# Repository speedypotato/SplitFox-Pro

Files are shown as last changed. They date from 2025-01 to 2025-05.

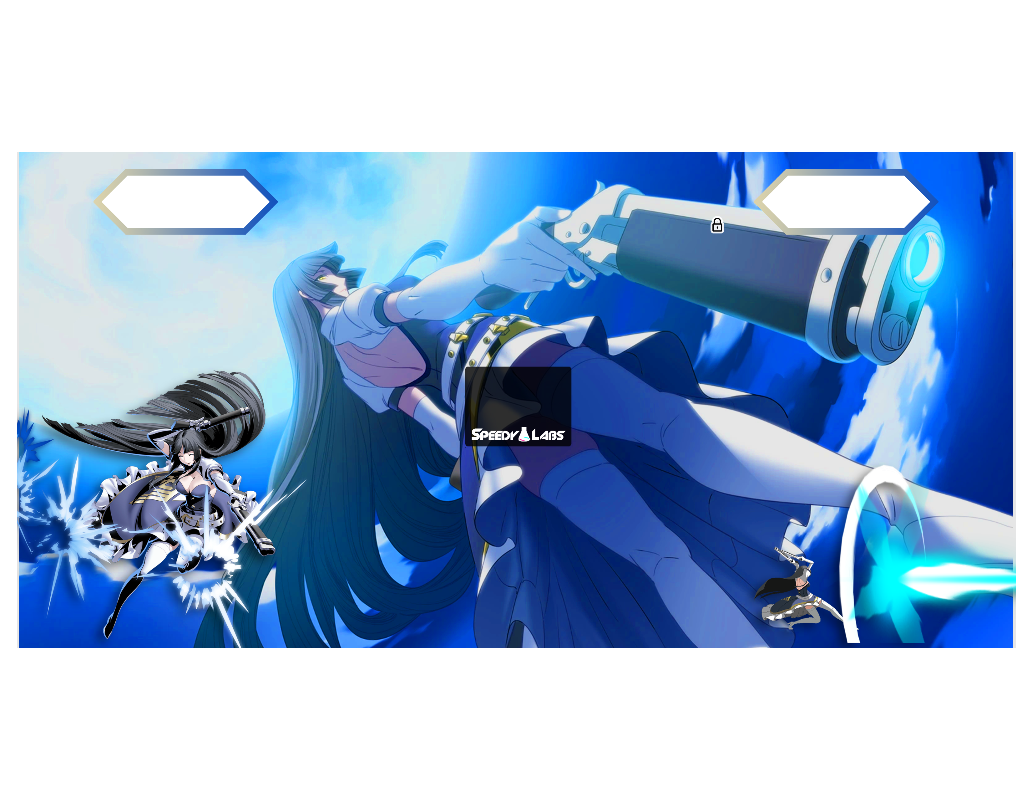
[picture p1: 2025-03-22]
art/legal_template/kaguya/speedy_labs_splitfox_template.png

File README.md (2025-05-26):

# SplitFox-Pro
Split-style Pro Leverless Controller

#### This work is licensed under a Creative Commons Attribution-NonCommercial-ShareAlike 4.0 International License.

### Prototype Run For Sale @ https://www.speedylabs.us/product/splitfox-pro-split-fighting-box-pro/ 

## What's the SplitFox Pro?
Speedy Labs introduces the SplitFox Pro - Split Fighting Box (Pro)!  This is a split layout leverless controller with 18 action buttons, 6 aux buttons, and a tournament lockout switch running on GP2040-CE.

### Design
When designing this, I had a few main goals in mind:
1. Split Layout
2. Embeddable PS Auth Dongle (non-protruding)
3. Standard or Mixbox support
4. USB C Daughterboard

Technically this would have been the LightFox Pro, but since I'm using choc v2 here due to the rumored discontinuation of Keychron LP Opticals it would feel wrong to call it that.  Hence SplitFox Pro.  The layout begins with the standard 12 button leverless layout.  I then took the 4 movement buttons and shifted them out one button space, creating the basic split layout.  I then added a button to each side of each thumb, as typical of many 16 button leverless layouts (except these only have one center thumb button, where SplitFox Pro has two).  Similarly, I added an extra button above the punch row as it's very typical to see one here in addition to a left hand pinky button because I believe that all fingers should be able to press a button at a moment's notice.

Some smaller goals, many carried over from the LightFox:
- Maintain acrylic top for artwork
- Aux buttons on both sides of controller for ease of use/preference
- OLED Display
- Mid-frame construction

### BOM
- PCBs
  - 1x SplitFox
  - 1x wasd or wasd-m
  - 1x usb-breakout
  - 1x usb-ext (optional)
- 1x OLED ZJY096-2864KSWEG41X
- Acrylics (2.5mm thickness)
  - 1x splitfox-bottom
  - 1x splitfox-top or splitfox-top-m
- CNC Aluminum (or 3D print if going for a cheaper build)
  - 1x splitfox-body
  - 1x splitfox-wasd-1_2mm or splitfox-wasd-m-1_2mm (both 1.2mm thick)
- 2x EVA Foam Feet splitfox-foot-2mm (or silicone, but it was too expensive for a small run for me)
- 23x m3x6 ultra low profile screws
- 2x m3 nut
- 18x shadow hunting switches (or any choc v2 switch)
- Keycaps
  - 4x 28.5mm
  - 14x 22.5 or 10x 22.5 + WASD (must be low profile mx stem compatible!!)
- Double sided mounting tape (Scotch 314H-MED is a good thickness for the oled in my tests)
- 2x ZH 7 Pin 10cm double headed wire (make sure you don't get the twisted cable version!! correct version e.g. https://ae01.alicdn.com/kf/S88d212727fc34138a45582e0e0a23c315.jpg)
- 3D prints
  - 1x usb-ext-bot
  - 1x usb-ext-top
  - 1x 93657A501_Nylon Unthreaded Spacer

Optionals, but things I would include normally:
- 1x 2mm hex wrench
- 1x 2m usb c cable
- 1x velcro cable tie
- 1x zipper case
- 1x shipping box
- 1x honson F5

### Basic Assembly Instructions
0. Flash SplitFox pcb
1. Plug in OLED and adhere with double sided mounting tape.
2. Plug both ZH cable into SplitFox pcb
3. Screw in SplitFox pcb into splitfox-body
4. Plug WASD ZH cable into wasd pcb
5. Screw wasd pcb into splitfox-body
6. Put splitfox-wasd-1_2mm into topside of splitfox-body, using 93657A501_Nylon Unthreaded Spacer, 1x m3x6, and 1x m3 nut to secure and sandwich together.
7. Insert shadow hunting switches.  Support sockets from backside when inserting to avoid damage.
8. Plug USB ZH cable into usb-breakout pcb
9. Screw in usb-breakout pcb into splitfox-body
10. Apply 2x splitfox-foot-2mm to splitfox-bottom
11. Screw in splitfox-bottom to splitfox-body
12. Add artwork cutout if desired
13. Screw in splitfox-top to splitfox-body

### Video Guides
SplitFox Pro Assembly & Mixbox Setup: https://youtu.be/-rr3WSn5i6s  
SplitFox Pro LED Setup (Beta): https://youtu.be/0wB09UQQ0kg

Done!  Be sure to post your builds on Discord @ https://discord.gg/MmuKd73XbY or Twitter/X and tag me @SpeedyPotato_

### Known Issues
v1.1 SplitFox fixes below issue by changing back to the crystal setup I used to use.  Could also be just a bad batch from v1 as I used a different PCBa for v1.1 too.

With v1, testing has gone fairly smoothly aside from one weird issue, where plugging in an auth dongle causes the controller to freeze/reboot.  If you leave the dongle plugged in all the time, this isn't an issue, but I hope to root cause it someday.  It might be the RP2040 crystal setup or the XC6206 being too weak, but both are also fairly tested in other controllers that don't have issues.  RP2040 crystal setup is new to me but is recommended in RP2040's hardware design guide.  XC6206 is used in production LightFox controllers and those have no issues hotplugging auth devices.

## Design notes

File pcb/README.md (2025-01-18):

# PCB

This is where the PCB source file(s) live

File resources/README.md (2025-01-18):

# Resources

This is where I dump important files during research, such as guides, datasheets, and reference circuits.

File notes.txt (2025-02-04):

shadow hunting switches + duelpad keycaps
- needs approx. 5mm above the plate to get correct height.  Maybe even lower.
- this means 2mm of alu cnc and 3mm of acryl

7 pin zh usb
1. gnd
2. gnd
3. vbus
4. d+
5. d-
6. vbus
7. gnd

7 pin zh wasd
1. rgb
2. right
3. up
4. down
5. left
6. vbus
7. gnd

and then on the mainboard, FLIP these!! due to how the cables are made

need to offset leds by 0.5mm inwards, 0.5mm downwards due to hotswap socket position

C41014 insertion depth: about 7.28
so assuming 10mm usb a male depth as standard, this means the usb should be 2.7mm away from board edge

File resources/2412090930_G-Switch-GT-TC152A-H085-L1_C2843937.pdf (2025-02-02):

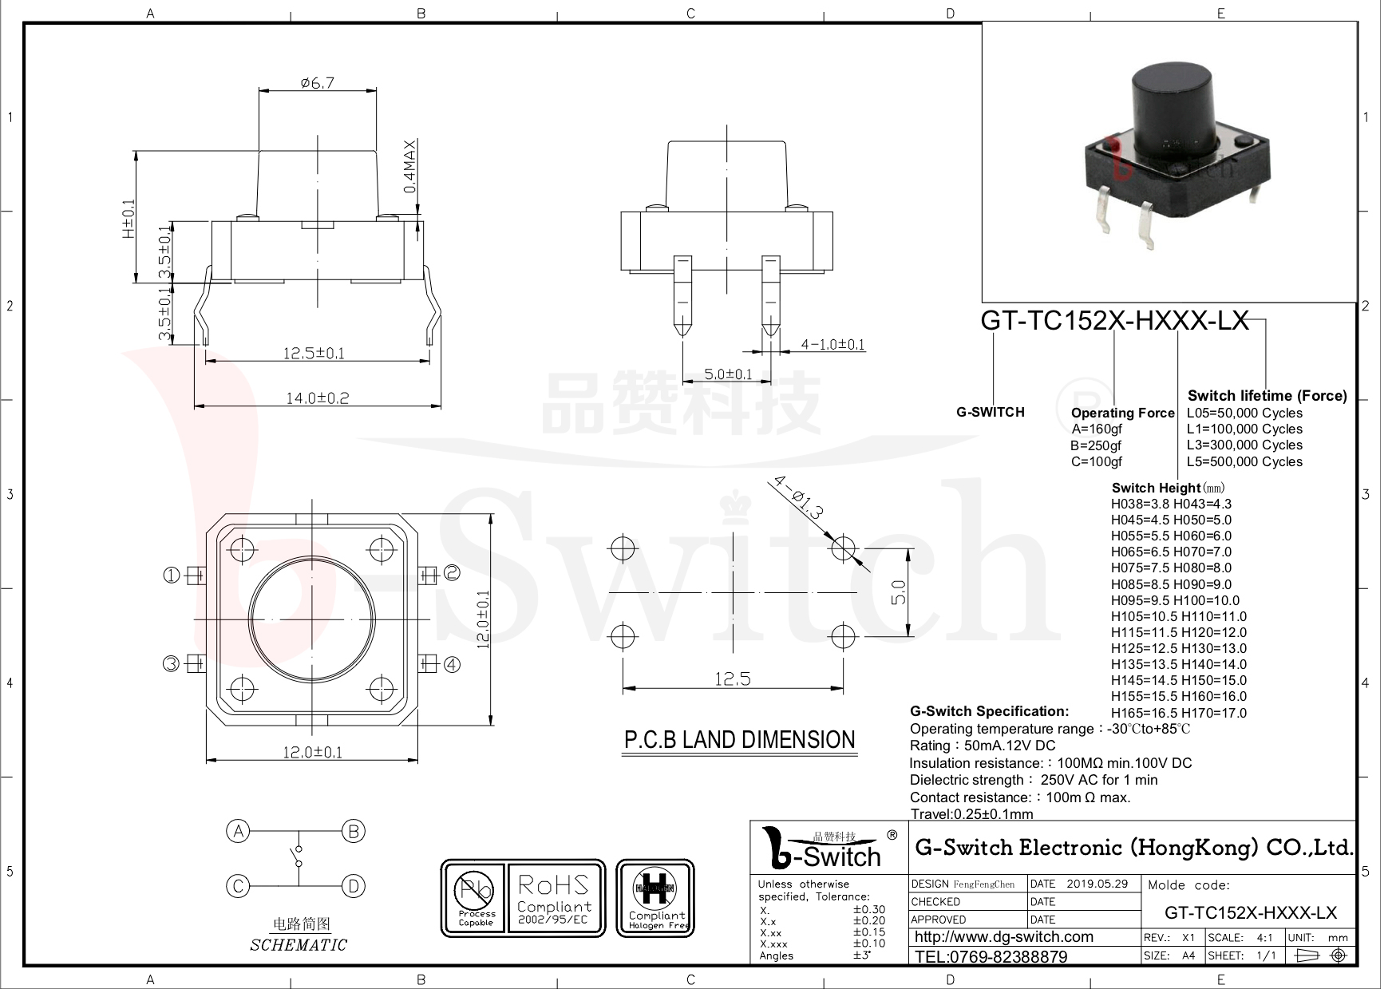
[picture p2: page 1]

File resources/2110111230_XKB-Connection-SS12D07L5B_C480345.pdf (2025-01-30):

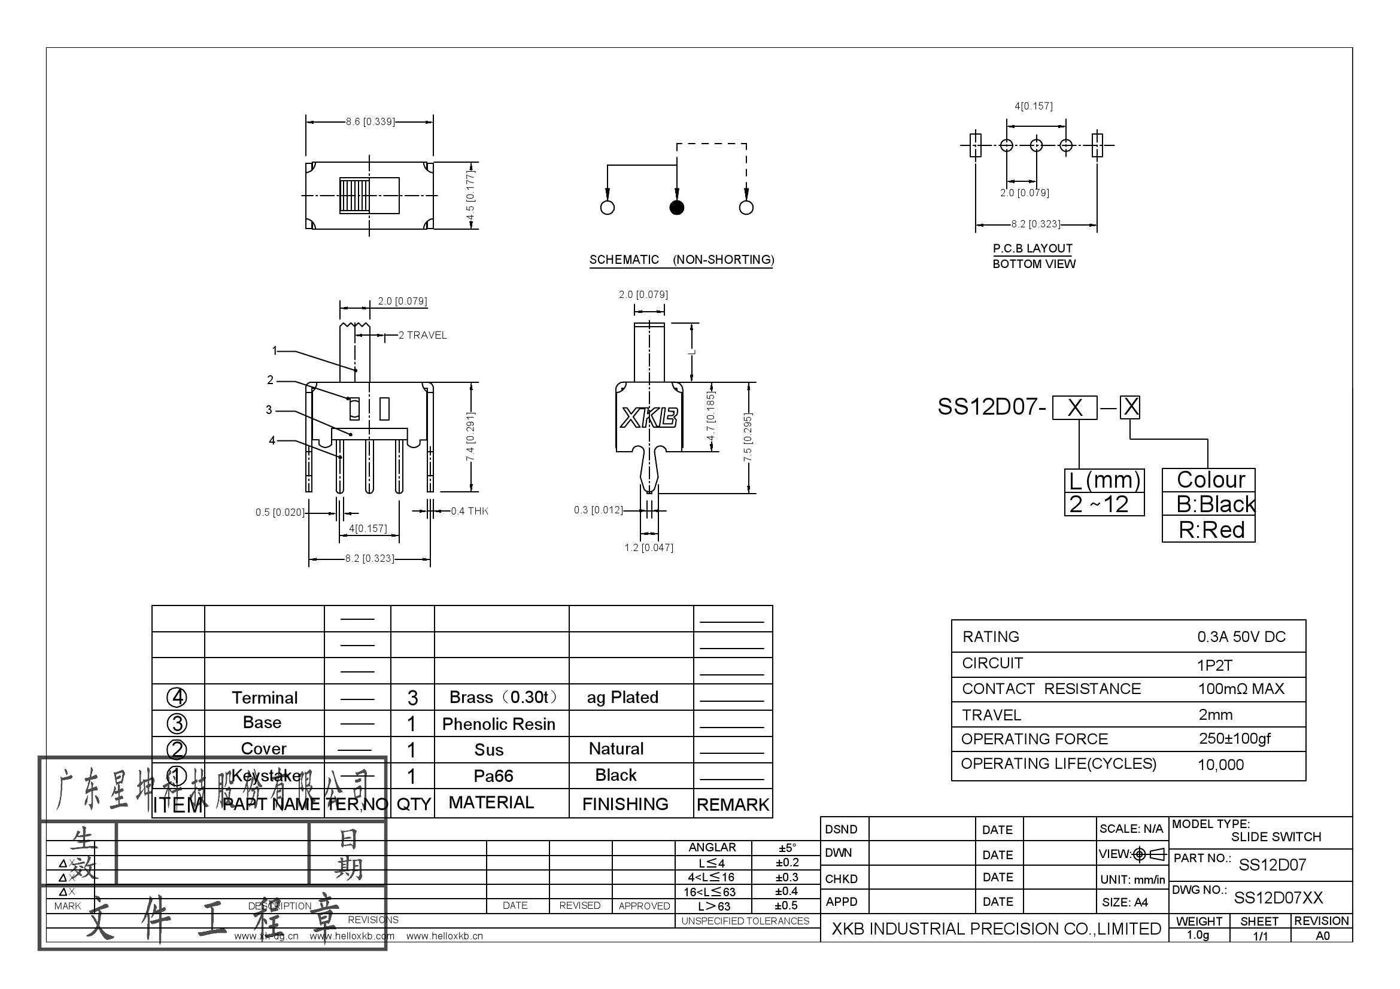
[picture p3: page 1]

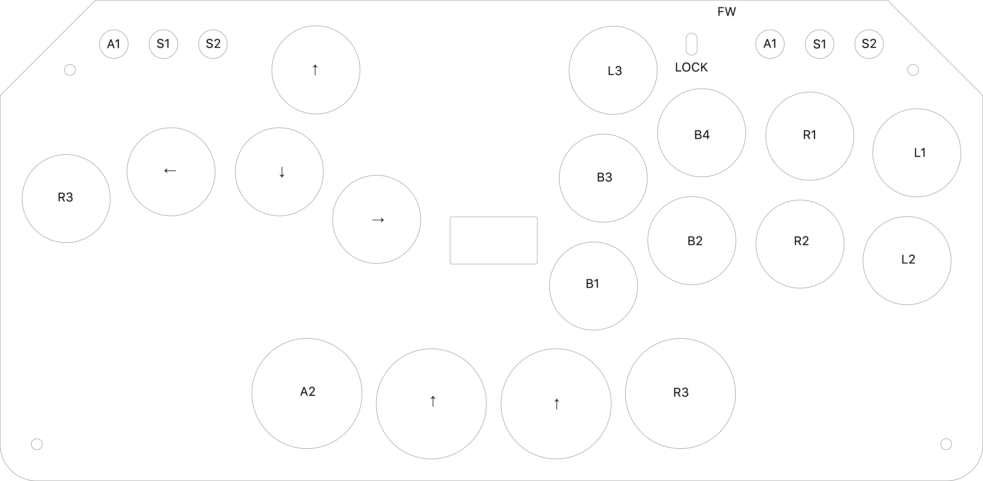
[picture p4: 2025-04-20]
docs/button layout.png

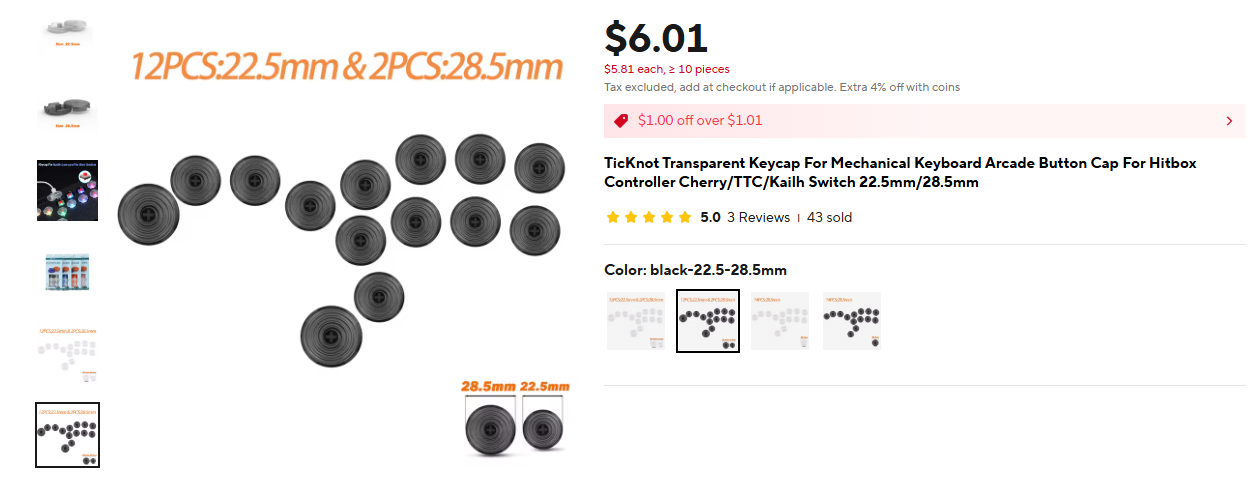
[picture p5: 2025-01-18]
video/screenshots/5_keycapsize.png

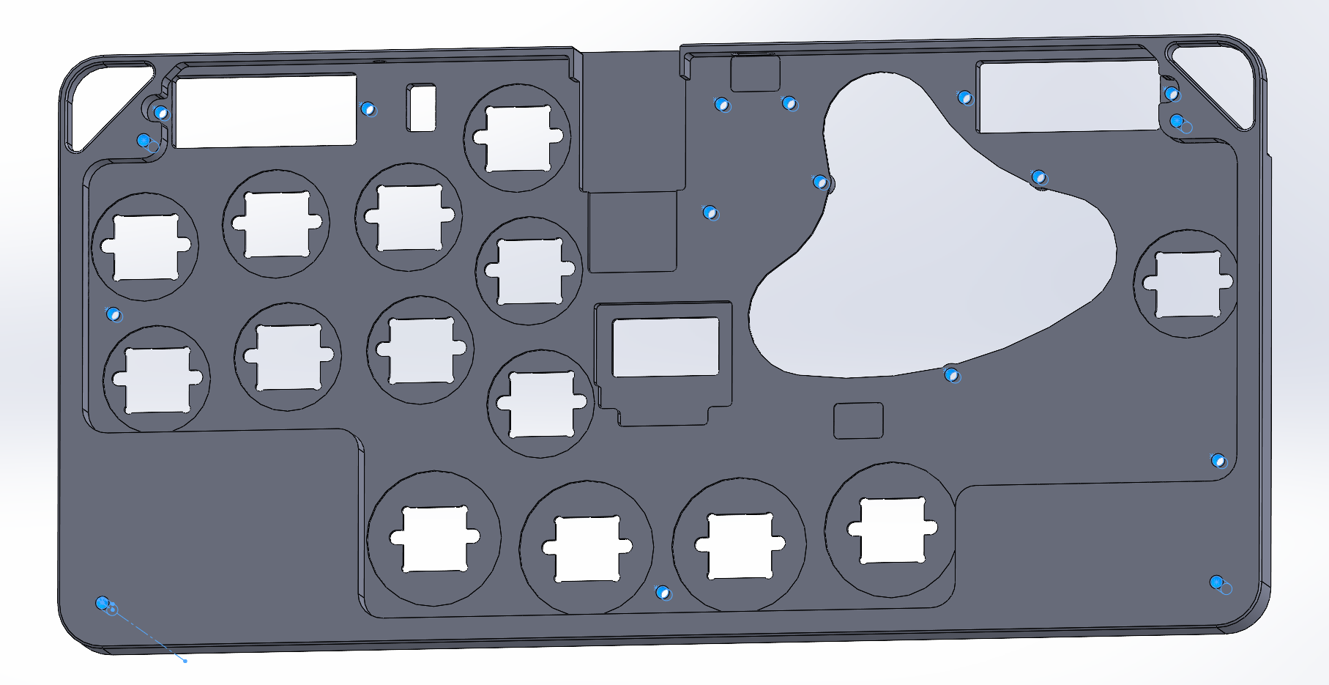
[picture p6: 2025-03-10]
cad/export/aluminum/splitfox-body-m3.png

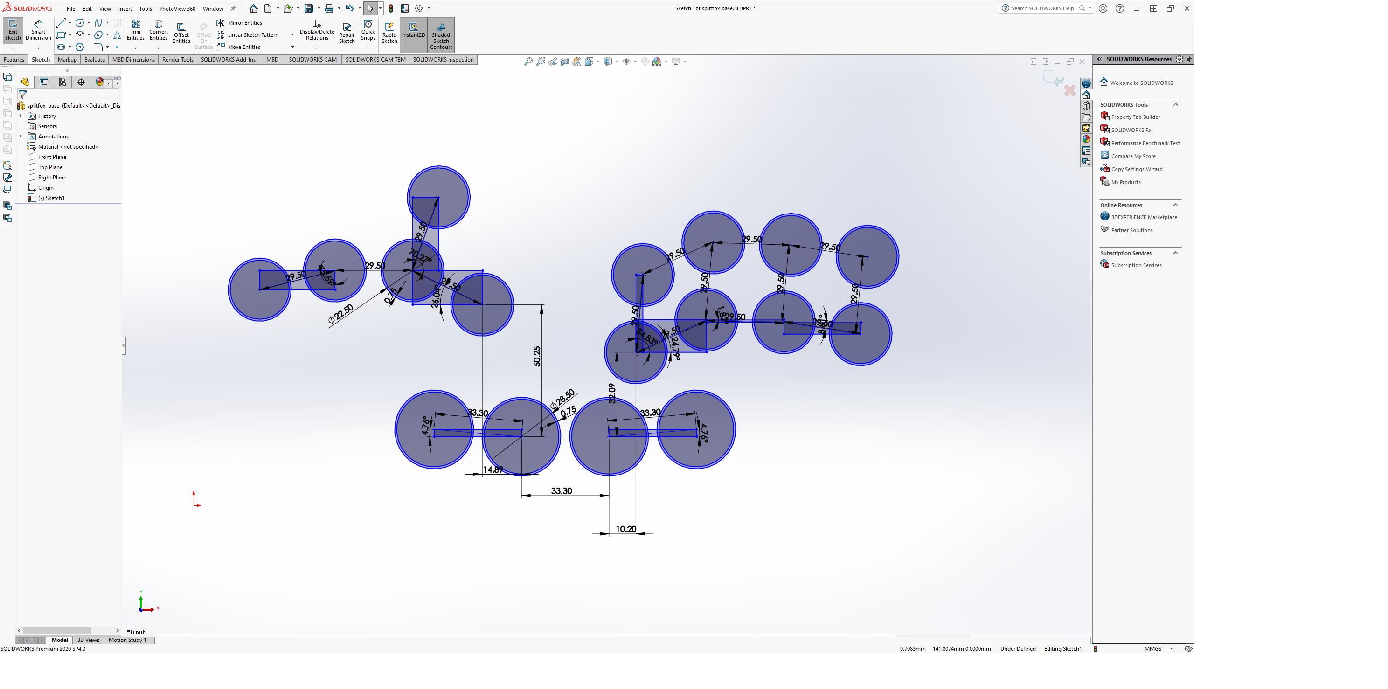
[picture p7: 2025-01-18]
video/screenshots/6_layout.png

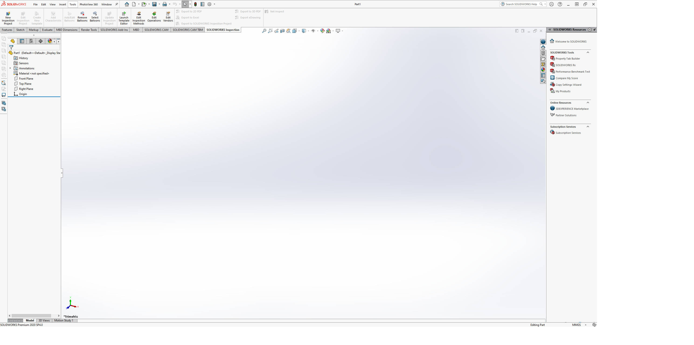
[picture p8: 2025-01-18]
video/screenshots/3_solidworks.png

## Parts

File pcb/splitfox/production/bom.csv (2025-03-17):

Designator | Footprint | Quantity | Value | LCSC Part #
C1, C10, C13, C16, C18, C19, C20, C21, C24, C25, C26, C27, C28, C29, C3, C30, C31, C32, C33, C34, C35, C36, C37, C38, C39, C40, C41, C42, C43, C44, C45, C46, C47, C48, C49, C50, C51, C52, C53, C54, C8 | 0402 | 41 | 100nF | C1525
C11, C12, C14, C15, C2, C4, C5, C9 | 0402 | 8 | 1uF | C52923
C17, C22 | 0402 | 2 | 4.7uF | C466620
C23 | 0402 | 1 | 2.2uF | C2976056
C6, C7 | 0402 | 2 | 30pF | C1570
CH1, CH10, CH11, CH12, CH13, CH14, CH2, CH3, CH4, CH5, CH6, CH7, CH8, CH9 | SW_choc_v2_HS_CPG135001S30_1u | 14 | choc_v1_SW_HS | C5333465
CN1, CN2 | CONN-SMD_S7B-ZR-SM4A-TF-LF-SN | 2 | S7B-ZR-SM4A-TF(LF)(SN)_C5118704 | C5118704
D1 | D_SOD-123 | 1 | ESD | C81598
F1, F2, F3 | 1206 | 3 | 500mA | C720075
FPC1 | FPC-SMD_30P-P0.50_0.5-30P-XJH2.0-043 | 1 | 0.5-30P XJH2.0 043 | C5373440
LED1, LED10, LED11, LED12, LED13, LED14, LED15, LED16, LED17, LED18, LED19, LED2, LED20, LED21, LED22, LED23, LED24, LED25, LED26, LED27, LED28, LED3, LED4, LED5, LED6, LED7, LED8, LED9 | LED_6028R | 28 | SK6812MINI-E | C5149201
R1, R2, R3, R4 | 0402 | 4 | 27R | C137890
R10 | 0402 | 1 | 910K | C25800
R11 | 0402 | 1 | 470R | C25117
R12 | 0402 | 1 | 4.7M | C474132
R13, R14 | 0402 | 2 | 5k1 | C25905
R5, R6 | 0402 | 2 | 1k | C11702
R7 | 0402 | 1 | 4K7 | C25900
R8, R9 | 0402 | 2 | 10k | C25744
SW1 | SW-SMD_TS24CA | 1 | TS24CA | C393942
SW2 | SW-TH_SS-12D07-X-X | 1 | SS-12D07-L5-B | C480345
SW3, SW4, SW5, SW6, SW7, SW8 | SW-TH_4P-L12.0-W12.0-P5.00-LS12.5 | 6 | GT-TC152A-H085-L1 | C2843937
U1 | RP2040-QFN-56 | 1 | RP2040 | C2040
U2 | SOT-23-5_L2.9-W1.6-P0.95-LS2.8-BR | 1 | SN74LV1T34DBVR | C100024
U3 | SOIC-8_5.23x5.23mm_P1.27mm | 1 | W25Q128JVS | C131025
U4 | SOT-23 | 1 | XC6206PxxxMR-Regulator_Linear | C5446
U5 | SOT-23-6 | 1 | USBLC6-2SC6 | C2827654
USB1 | USB-A-SMD_C41014 | 1 | USB-AF-90-10X15.7-H5.72-CB | C41014
USBC1 | USB-C_SMD-TYPE-C-31-M-12 | 1 | TYPE-C-31-M-12 | C165948
Y1 | Crystal_SMD_3225-4Pin_3.2x2.5mm | 1 | 12MHz | C9002

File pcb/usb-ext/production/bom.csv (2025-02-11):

Designator | Footprint | Quantity | Value | LCSC Part #
USB1 | USB-SMD_AM180CB | 1 | AM 180°CB | C2681565
USB2 | USB-A-SMD_C41014 | 1 | USB-AF-90-10X15.7-H5.72-CB | C41014

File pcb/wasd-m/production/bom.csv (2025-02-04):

Designator | Footprint | Quantity | Value | LCSC Part #
C1, C2, C3, C4 | 0402 | 4 | 100nF | C1525
CH1, CH2, CH3, CH4 | SW_choc_v2_HS_CPG135001S30_1u | 4 | choc_v1_SW_HS | C5333465
CN1 | CONN-SMD_S7B-ZR-SM4A-TF-LF-SN | 1 | S7B-ZR-SM4A-TF(LF)(SN)_C5118704 | C5118704
LED1, LED2, LED3, LED4 | LED_choc_6028R | 4 | choc_SK6812MINI-E | C5149201

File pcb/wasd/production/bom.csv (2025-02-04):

Designator | Footprint | Quantity | Value | LCSC Part #
C1, C2, C3, C4, C5, C6, C7, C8 | 0402 | 8 | 100nF | C1525
CH1, CH2, CH3, CH4 | SW_choc_v2_HS_CPG135001S30_1u | 4 | choc_v1_SW_HS | C5333465
CN1 | CONN-SMD_S7B-ZR-SM4A-TF-LF-SN | 1 | S7B-ZR-SM4A-TF(LF)(SN)_C5118704 | C5118704
LED1, LED2, LED3, LED4, LED5, LED6, LED7, LED8 | LED_choc_6028R | 8 | choc_SK6812MINI-E | C5149201

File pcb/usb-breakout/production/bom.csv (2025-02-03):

Designator | Footprint | Quantity | Value | LCSC Part #
CN1 | CONN-SMD_S7B-ZR-SM4A-TF-LF-SN | 1 | S7B-ZR-SM4A-TF(LF)(SN)_C5118704 | C5118704
R1, R2 | 0402 | 2 | 5k1 | C25905
USBC1 | USB-C_SMD-TYPE-C-31-M-12 | 1 | TYPE-C-31-M-12 | C165948

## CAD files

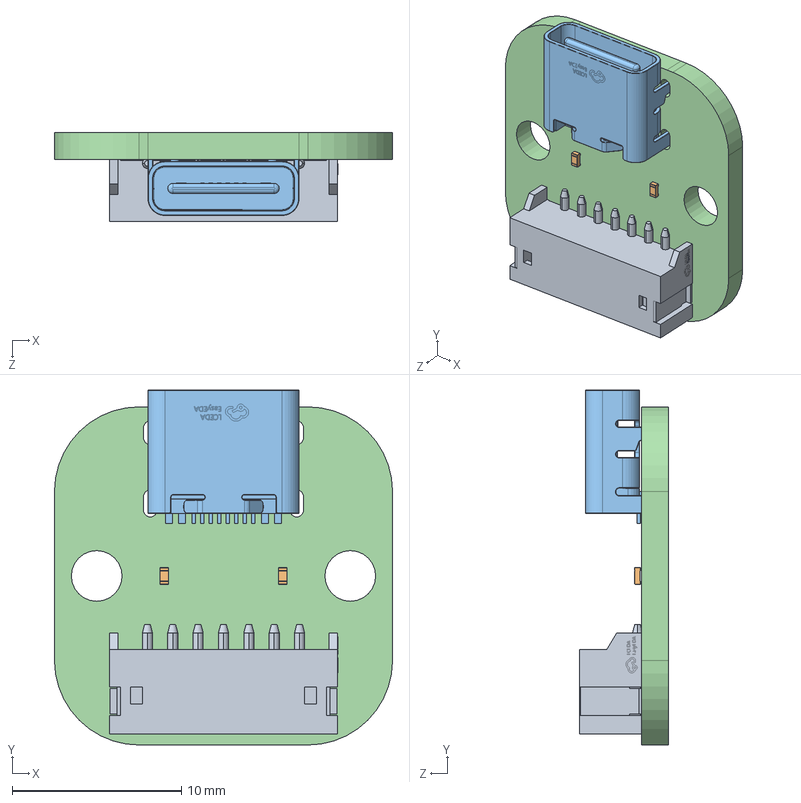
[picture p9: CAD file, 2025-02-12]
pcb/usb-breakout/usb-breakout-pcb.SLDASM
20.0 x 21.0 x 5.25 mm
CONN-SMD_S7B-ZR-SM4A-TF-LF-SN-1.step
R_0402_1005Metric-1.step x 2
USB-C_SMD-TYPE-C-31-M-12-2.step
_autosave-usb-breakout_PCB.step

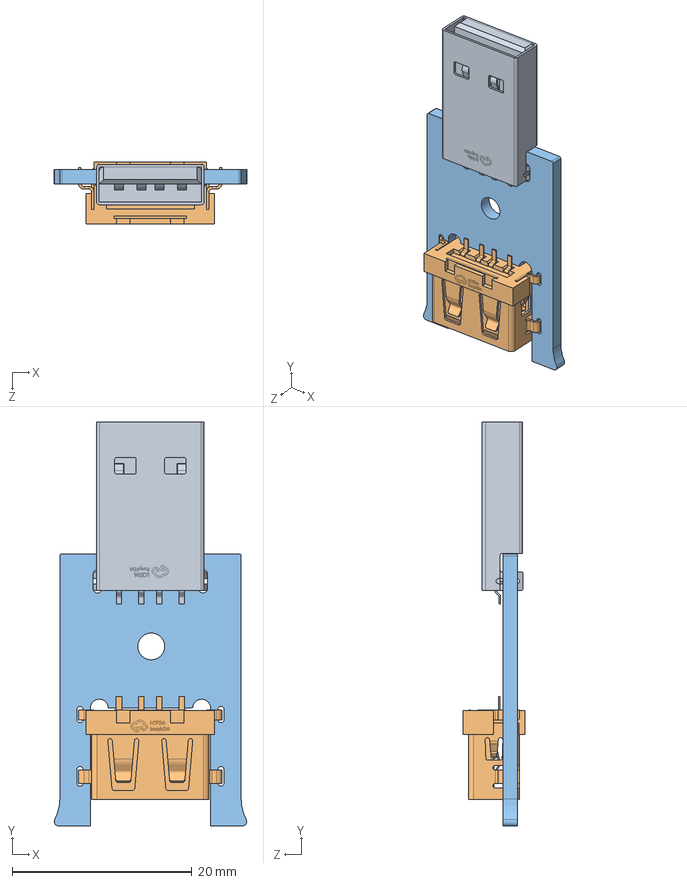
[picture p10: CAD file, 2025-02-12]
pcb/usb-ext/usb-ext-pcb.SLDASM
21.4 x 45.0 x 6.88 mm
USB-SMD_AM180CB-0.step
USB-A-SMD_4P-L13.1-W10.0-H5.7-LS15.7-5.step
_autosave-usb-ext_PCB.step

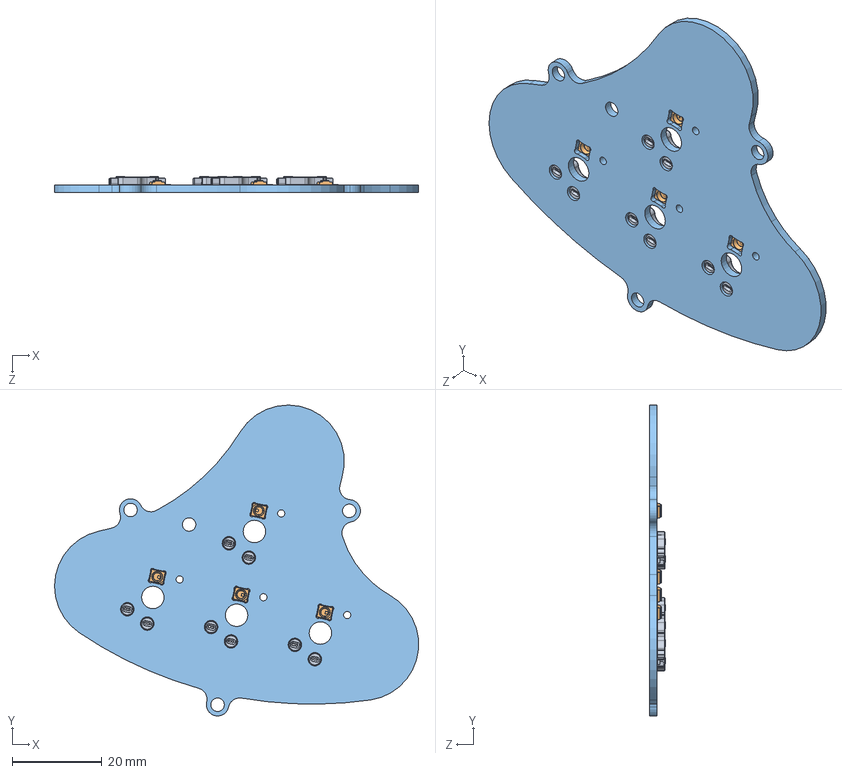
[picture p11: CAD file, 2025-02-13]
pcb/wasd-m/wasd-m-pcb.SLDASM
81.0 x 69.1 x 3.49 mm
HS_Kailh_Choc v4.step x 4
LED_SK6812MINI-E v2.step x 4
_autosave-wasd-m_PCB.step

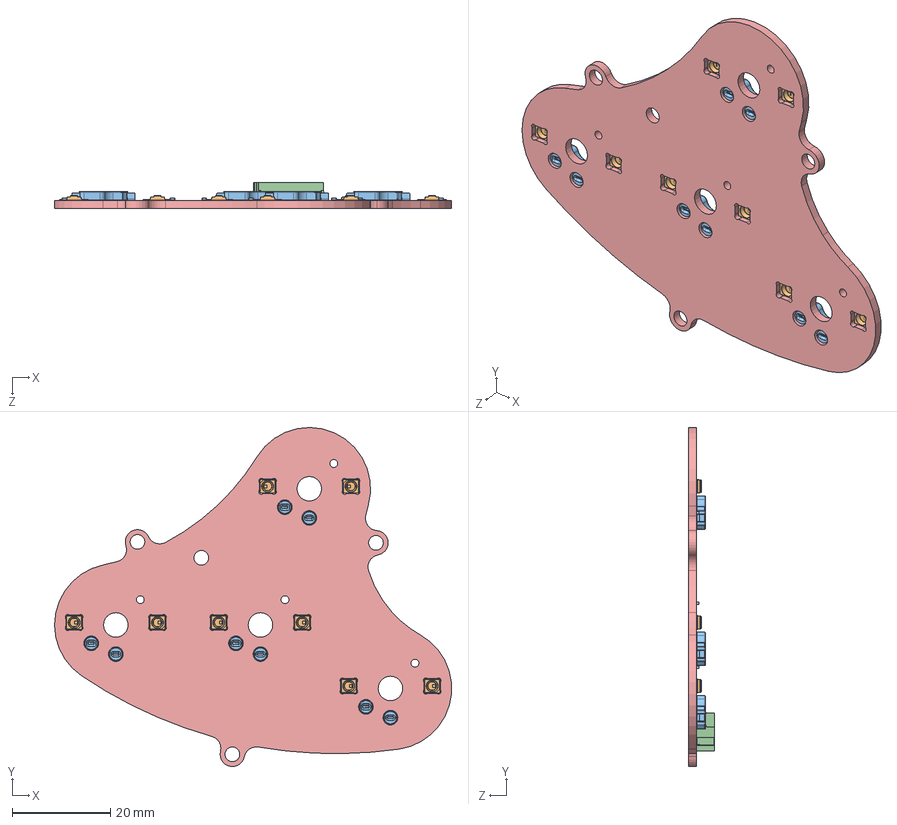
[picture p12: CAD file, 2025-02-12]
pcb/wasd/wasd-pcb.SLDASM
81.0 x 69.1 x 5.25 mm
C_0402_1005Metric-0.step x 8
LED_SK6812MINI-E v2.step x 8
HS_Kailh_Choc v4.step x 4
CONN-SMD_S7B-ZR-SM4A-TF-LF-SN-1.step
_autosave-wasd_PCB.step

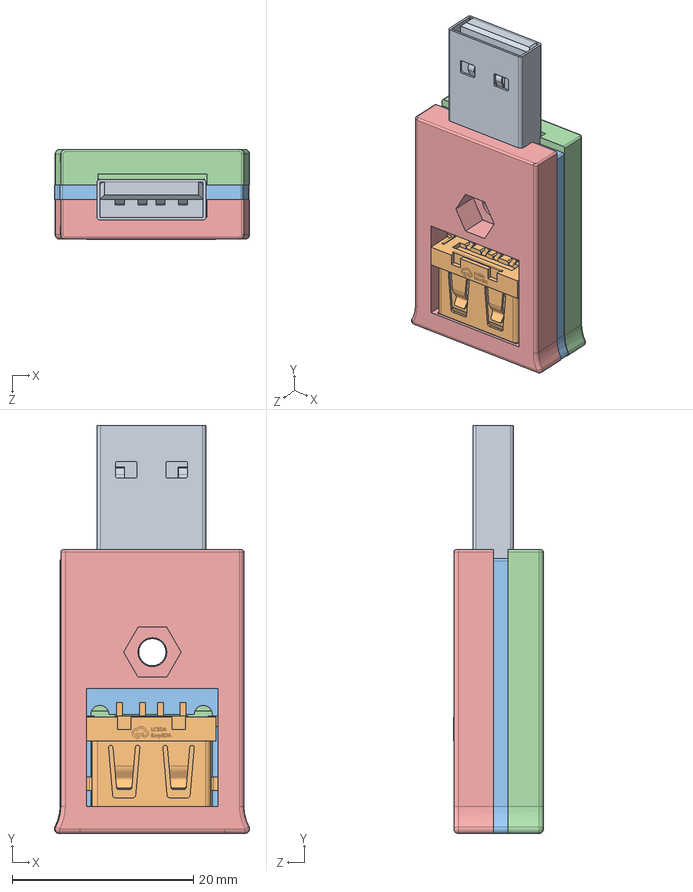
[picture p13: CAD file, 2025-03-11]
cad/usb-ext-assem.SLDASM
21.5 x 45.0 x 9.93 mm
USB-SMD_AM180CB-0.step
USB-A-SMD_4P-L13.1-W10.0-H5.7-LS15.7-5.step
_autosave-usb-ext_PCB.step
usb-ext-bot
usb-ext-top

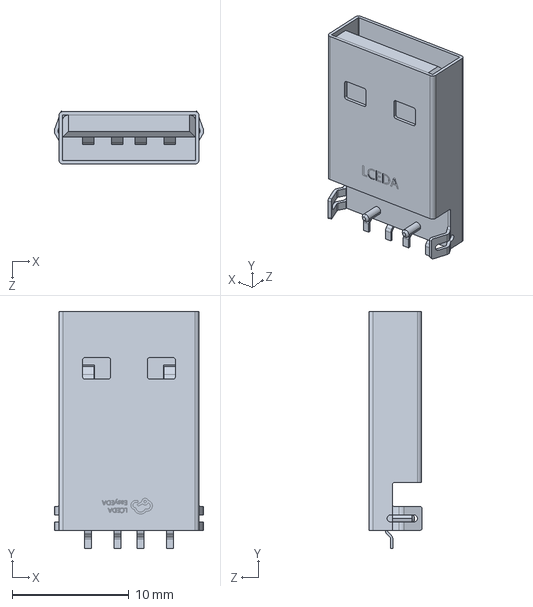
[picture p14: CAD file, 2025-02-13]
cad/usb-ext.SLDASM
12.8 x 20.3 x 4.55 mm

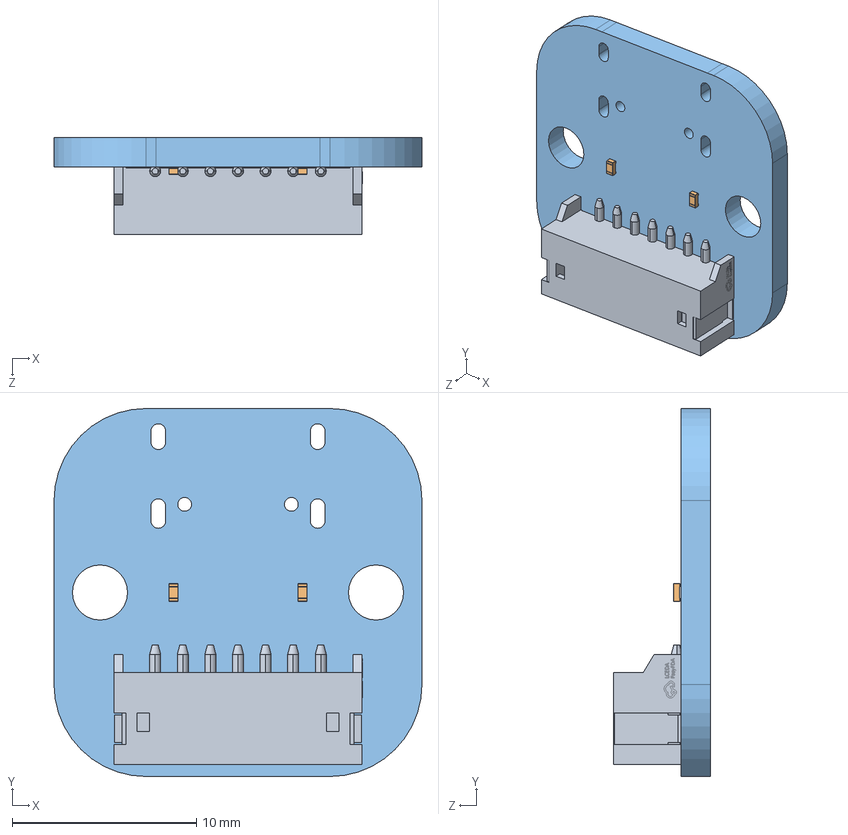
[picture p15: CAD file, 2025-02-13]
cad/usb-breakout.SLDASM
20.0 x 20.0 x 5.25 mm
CONN-SMD_S7B-ZR-SM4A-TF-LF-SN-7.step
R_0402_1005Metric-1.step x 2
usb-breakout_PCB.step

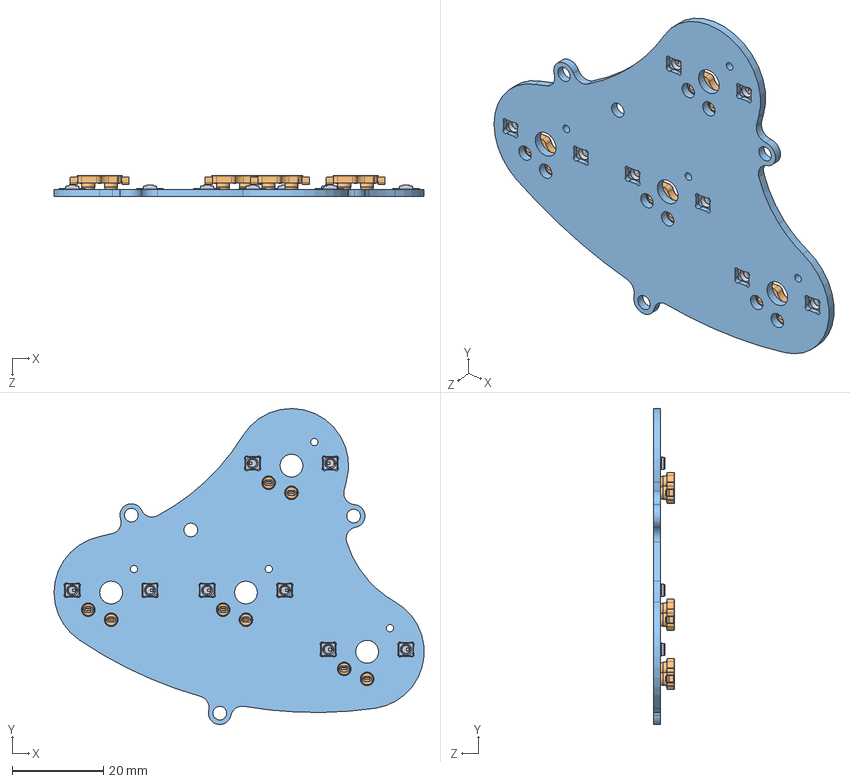
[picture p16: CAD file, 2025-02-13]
cad/wasd.SLDASM
81.0 x 69.1 x 4.69 mm
LED_SK6812MINI-E v2.step x 8
HS_Kailh_Choc v4.step x 4
_autosave-wasd_PCB.step

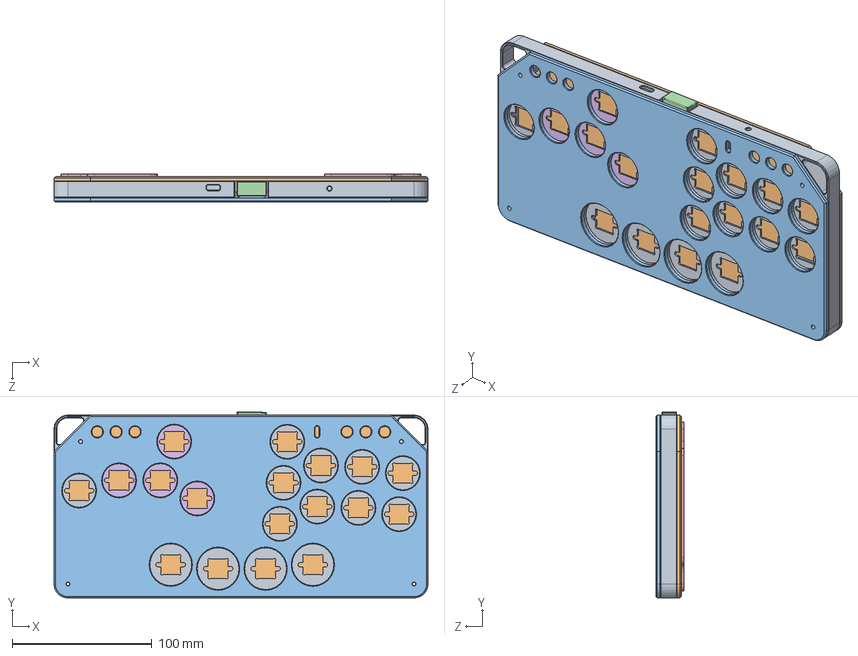
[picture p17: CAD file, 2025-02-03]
cad/splitfox.SLDASM
267.8 x 133.1 x 20.3 mm
splitfox-body
splitfox-bottom
splitfox-top
honson-f5
splitfox-foot
splitfox-wasd

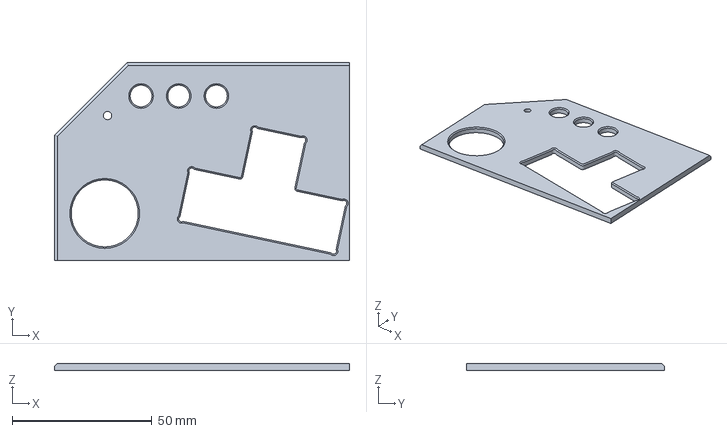
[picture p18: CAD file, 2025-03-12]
cad/3d-print-test/splitfox-top-m-2_5.3MF
105.7 x 70.9 x 2.50 mm

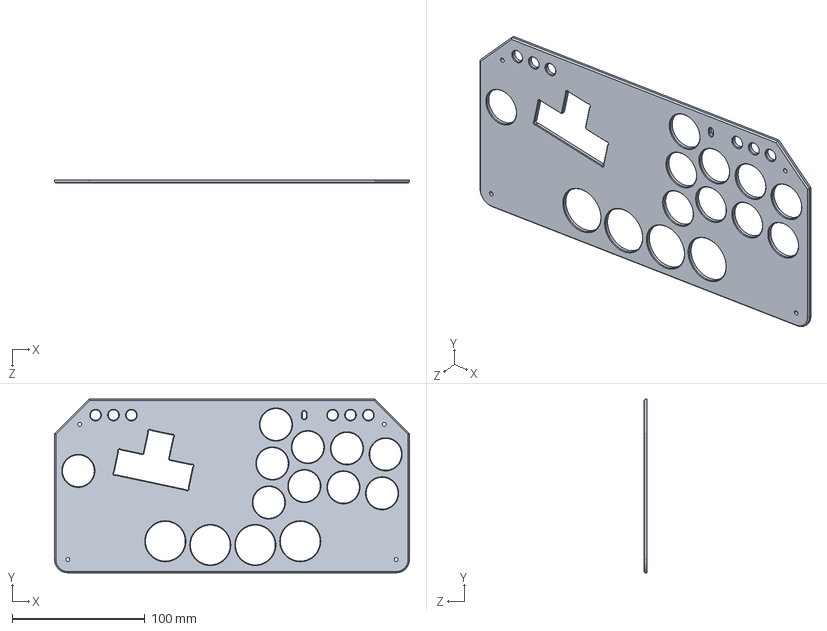
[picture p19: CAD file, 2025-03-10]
cad/export/acrylic/splitfox-top-m.STEP
267.8 x 131.0 x 2.50 mm

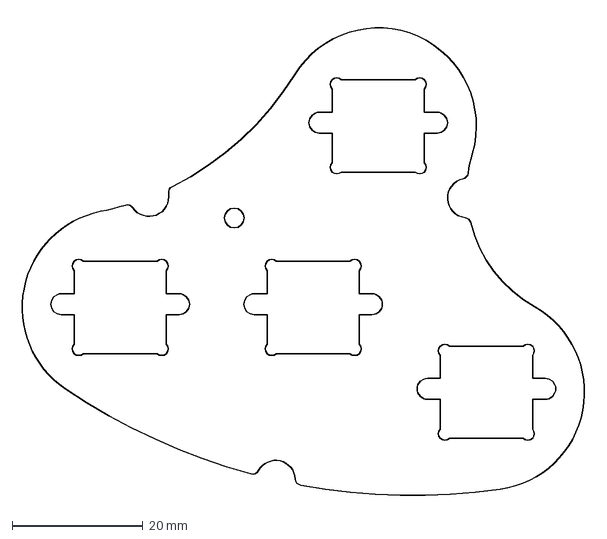
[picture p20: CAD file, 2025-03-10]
cad/export/aluminum/splitfox-wasd-1_2mm.DXF
87.8 x 73.8 mm

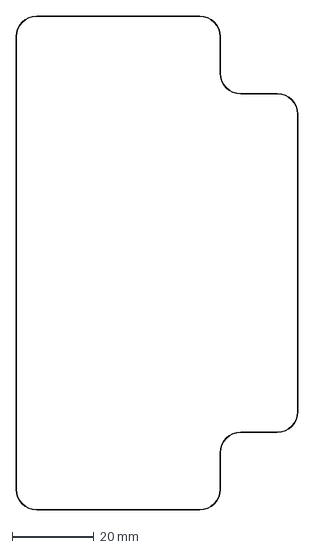
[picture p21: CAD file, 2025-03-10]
cad/export/rubber/splitfox-foot-2mm.DXF
69.0 x 121.0 mm

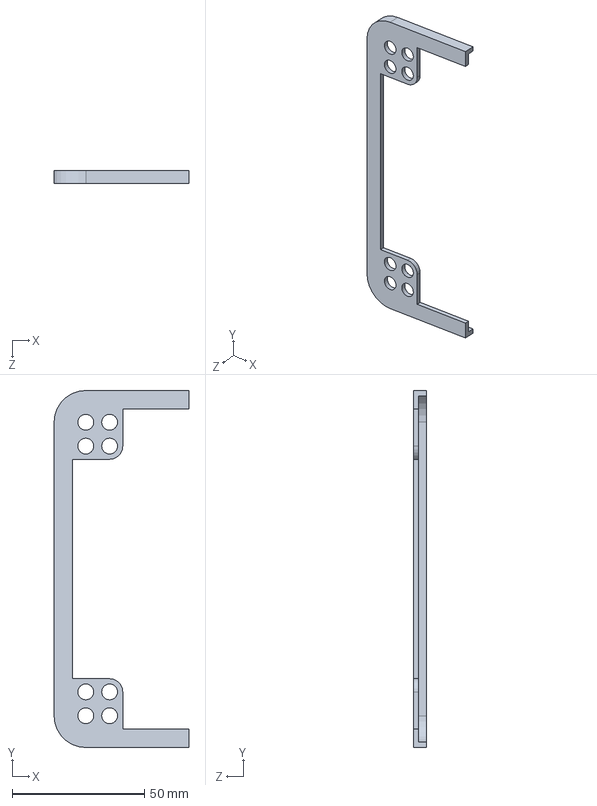
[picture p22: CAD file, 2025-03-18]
cad/splitfox-foot-tool.SLDPRT
51.0 x 135.0 x 5.00 mm

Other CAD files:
pcb/wasd/wasd.step
resources/R16-facetemplate.dwg
resources/reference/multra.SLDPRT
cad/3d-print-test/splitfox-foot.3MF
cad/3d-print-test/splitfox-body - Copy (2).3MF
cad/3d-print-test/splitfox-body - Copy (2).SLDPRT
cad/3d-print-test/splitfox-body - Copy (3).3MF
cad/3d-print-test/splitfox-body - Copy (3).SLDPRT
cad/3d-print-test/splitfox-body - Copy.3MF
cad/3d-print-test/splitfox-body - Copy.SLDPRT
cad/3d-print-test/splitfox-body.3MF
cad/3d-print-test/splitfox-body.SLDPRT
cad/3d-print-test/splitfox-bottom.DXF
cad/3d-print-test/splitfox-top-m.DXF
cad/3d-print-test/splitfox-top.DXF
cad/3d-print-test/splitfox-wasd-m.3MF
cad/3d-print-test/splitfox-wasd.3MF
cad/export/3dprint/93657A501_Nylon Unthreaded Spacer.3MF
cad/export/3dprint/splitfox-foot-tool.3MF
cad/export/3dprint/usb-ext-bot.3MF
cad/export/3dprint/usb-ext-top.3MF
cad/export/acrylic/splitfox-bottom.STEP
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

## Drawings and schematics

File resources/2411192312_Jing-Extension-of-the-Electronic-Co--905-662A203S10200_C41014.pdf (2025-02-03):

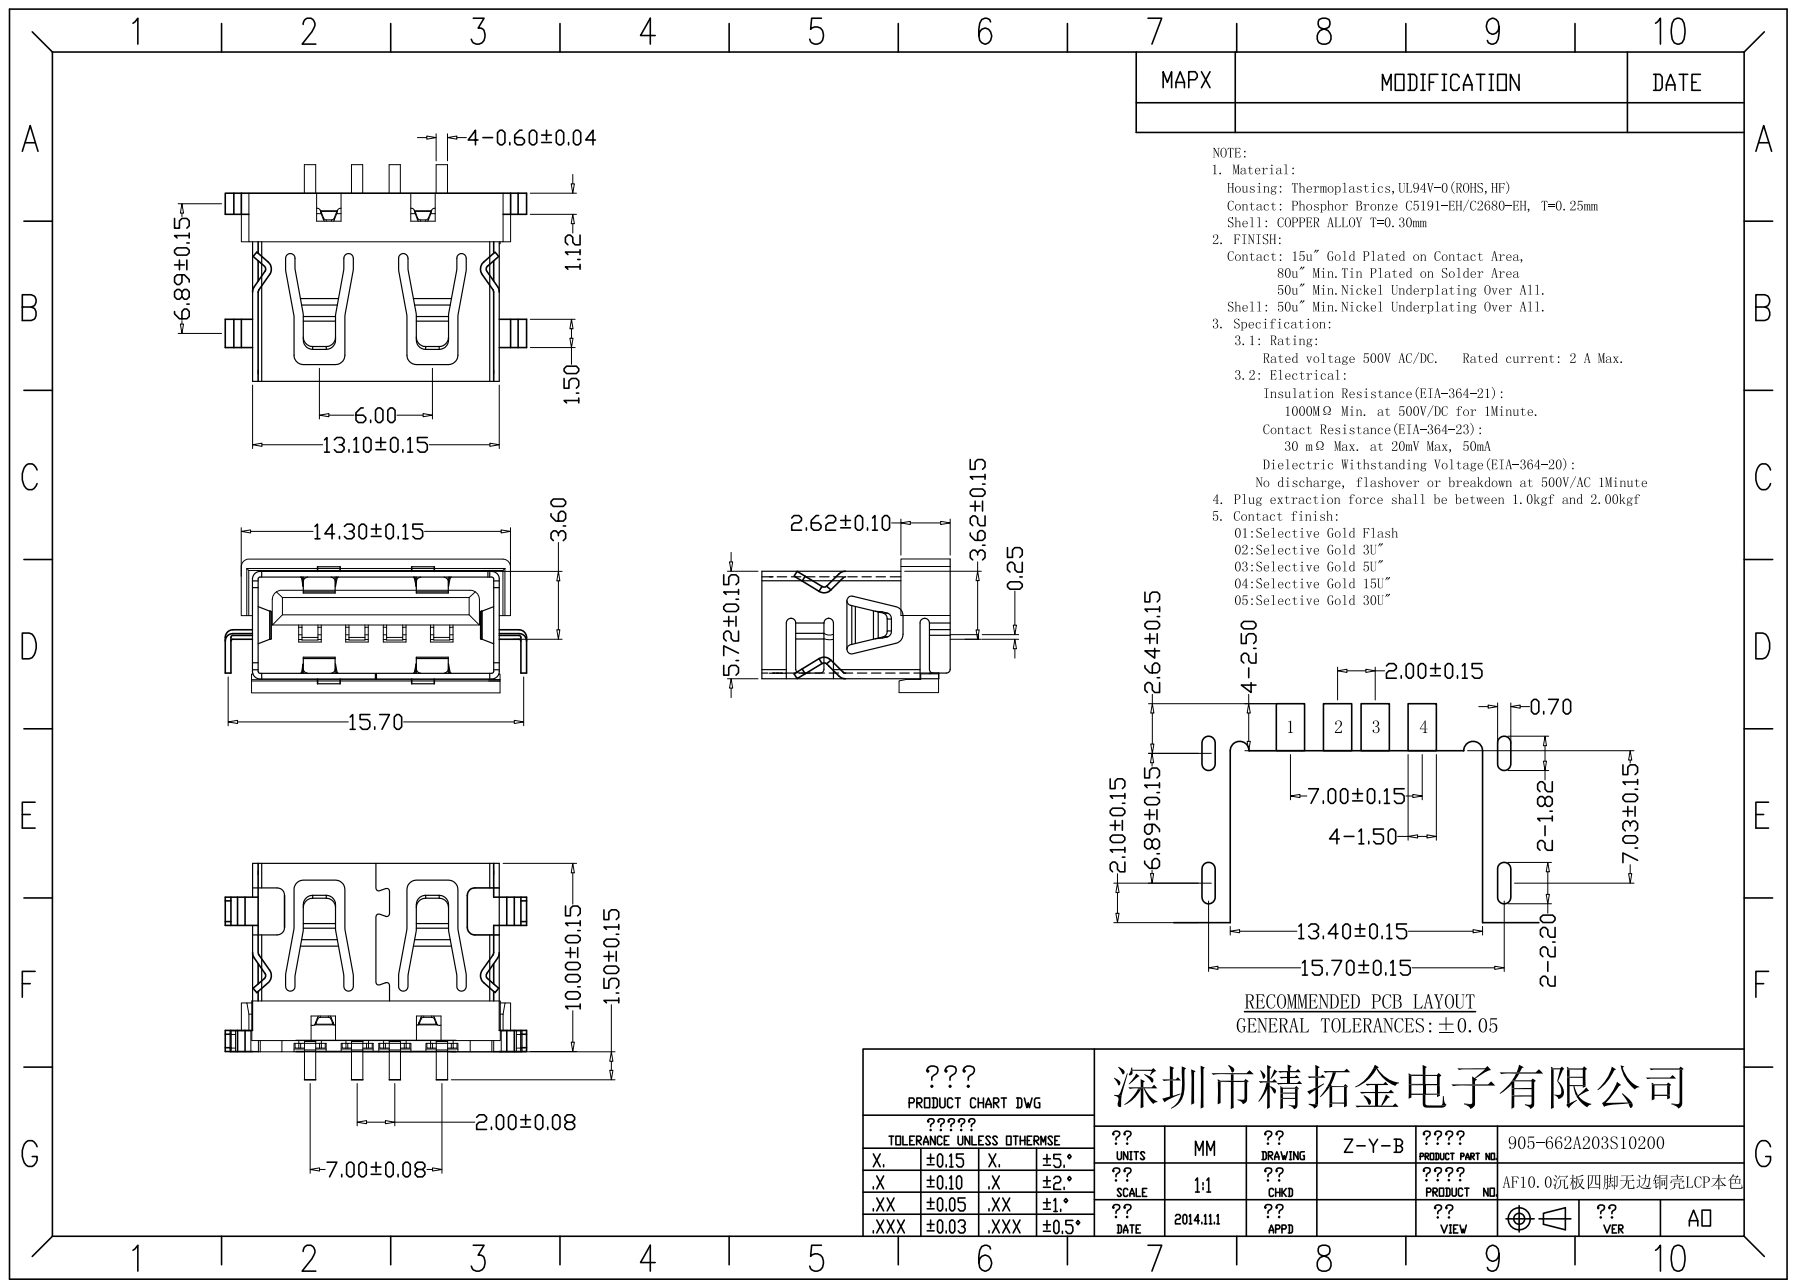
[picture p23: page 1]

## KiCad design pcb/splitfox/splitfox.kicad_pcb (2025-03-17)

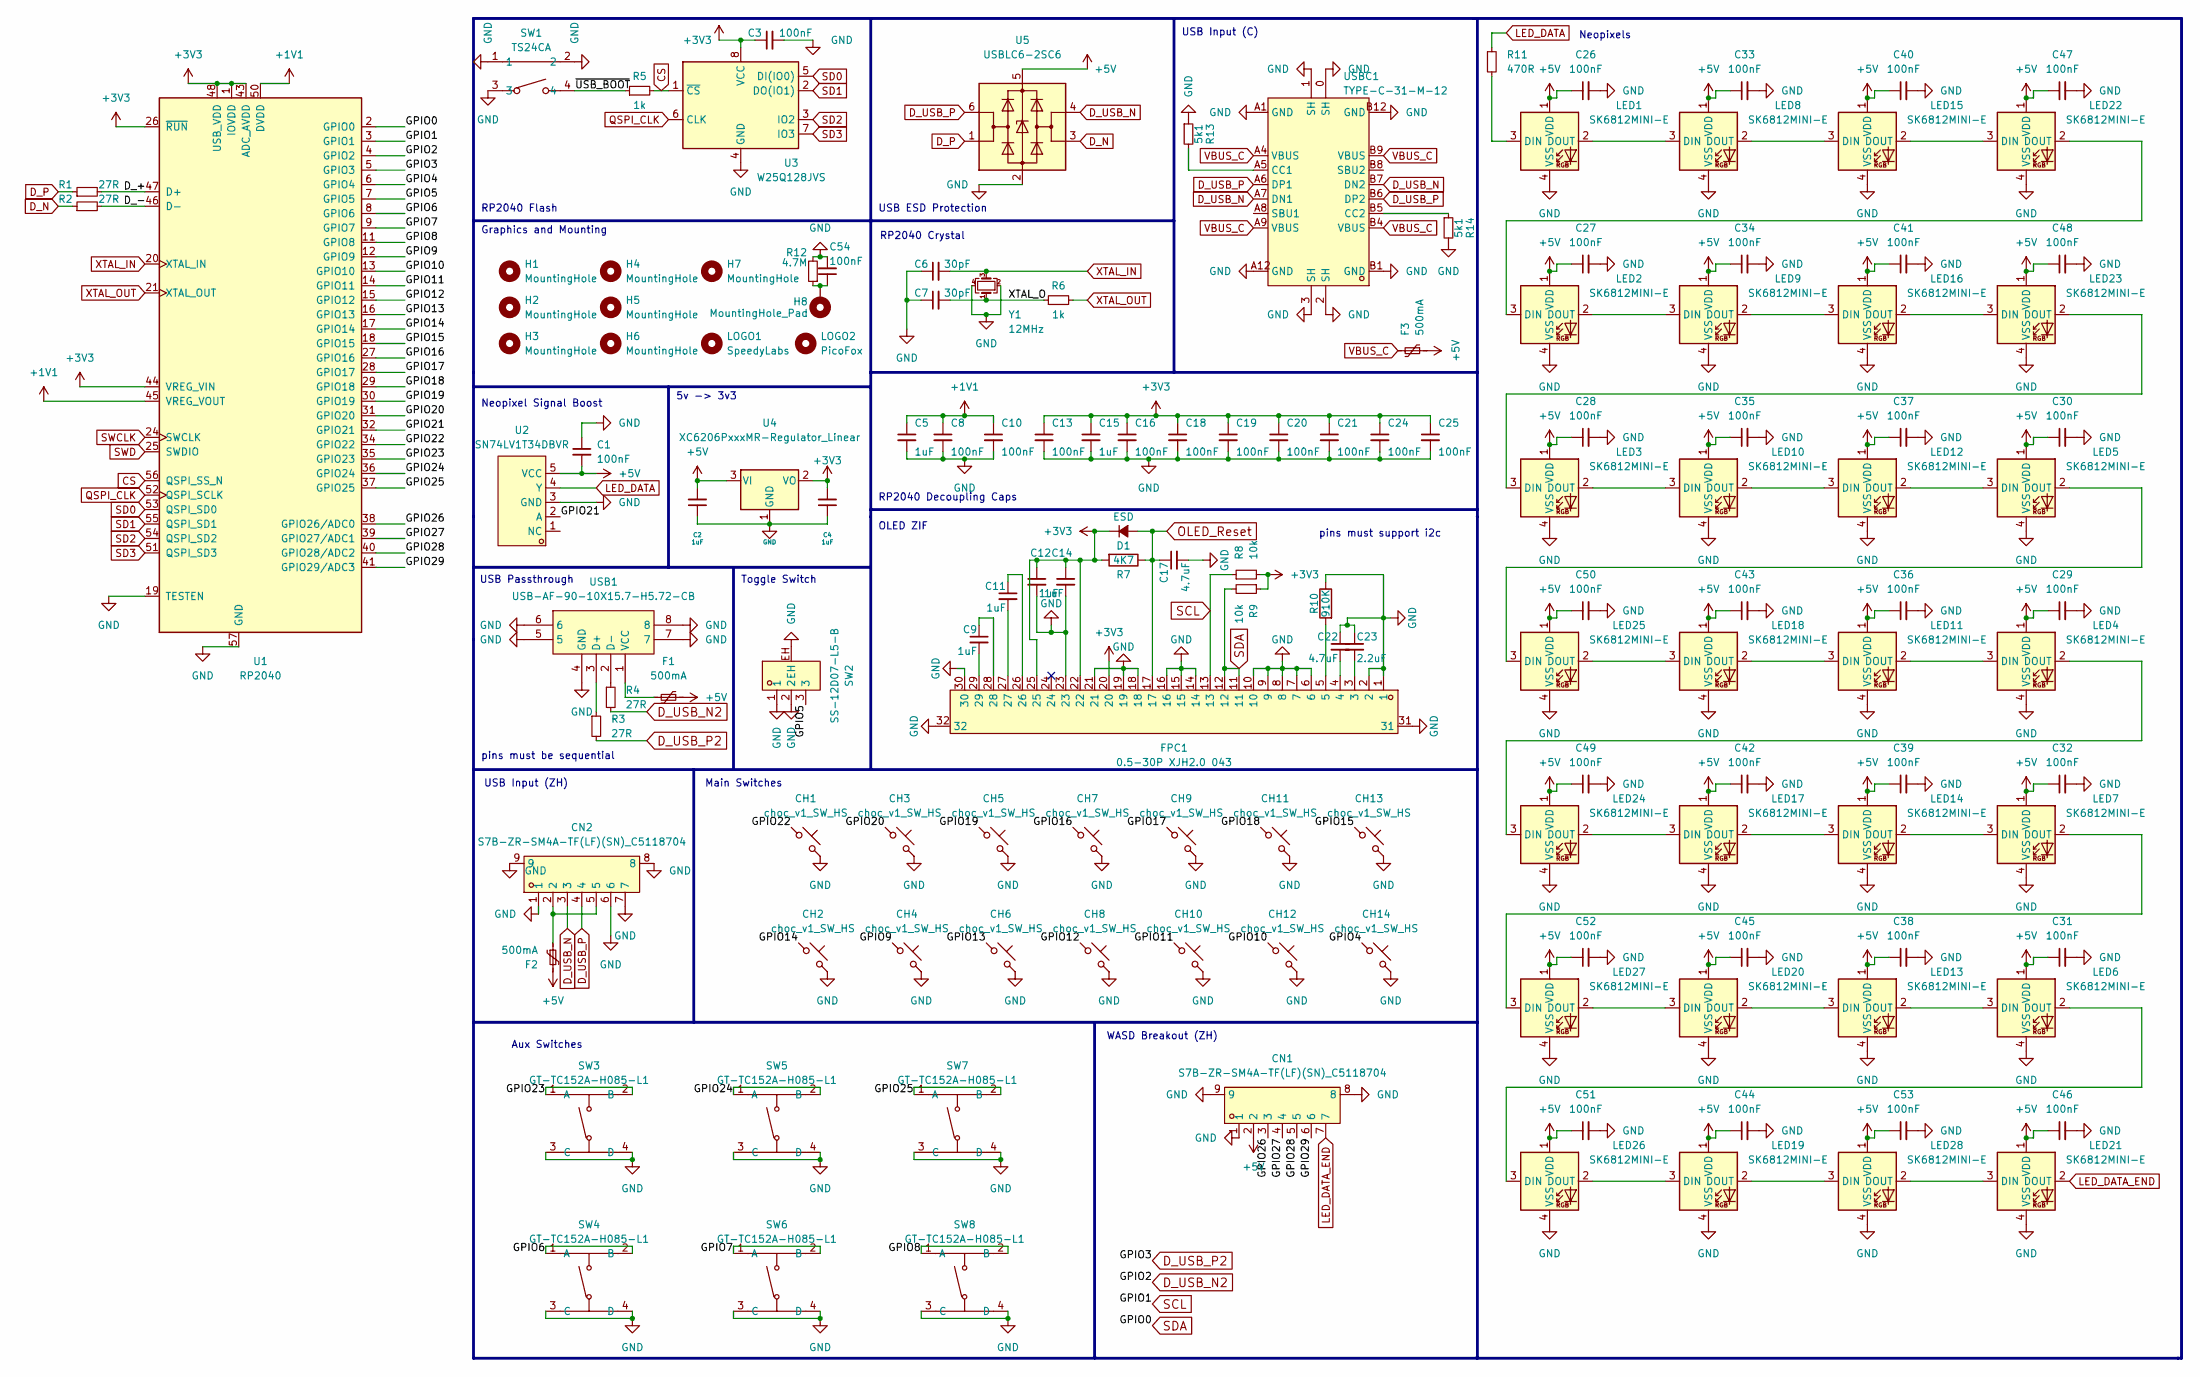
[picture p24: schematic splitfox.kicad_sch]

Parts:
C1, C3, C8, C10, C13, C16, C18, C19, C20, C21, C24, C25, C26, C27, C28, C29, C30, C31, C32, C33, C34, C35, C36, C37, C38, C39, C40, C41, C42, C43, C44, C45, C46, C47, C48, C49, C50, C51, C52, C53, C54: 100nF; C_0402_1005Metric; LCSC C1525
C2, C4, C5, C9, C11, C12, C14, C15: 1uF; C_0402_1005Metric; LCSC C52923
C6, C7: 30pF; C_0402_1005Metric; LCSC C1570
C17, C22: 4.7uF; C_0402_1005Metric; LCSC C466620
C23: 2.2uF; C_0402_1005Metric; LCSC C2976056
CH1, CH2, CH3, CH4, CH5, CH6, CH7, CH8, CH9, CH10, CH11, CH12, CH13, CH14: choc_v1_SW_HS; SW_choc_v2_HS_CPG135001S30_1u; LCSC C5333465
CN1, CN2: S7B-ZR-SM4A-TF(LF)(SN)_C5118704; CONN-SMD_S7B-ZR-SM4A-TF-LF-SN; LCSC Part C5118704
D1: ESD; D_SOD-123; LCSC C81598
F1, F2, F3: 500mA; Fuse_1206_3216Metric; LCSC C720075
FPC1: 0.5-30P XJH2.0 043; FPC-SMD_30P-P0.50_0.5-30P-XJH2.0-043; LCSC Part C5373440
H1, H2, H3, H4, H5, H6, H7: MountingHole; MountingHole_3mm
H8: MountingHole_Pad; MountingHole_3mm_Pad
LED1, LED2, LED3, LED4, LED5, LED6, LED7, LED8, LED9, LED10, LED11, LED12, LED13, LED14, LED15, LED16, LED17, LED18, LED19, LED20, LED21, LED22, LED23, LED24, LED25, LED26, LED27, LED28: SK6812MINI-E; LED_6028R; LCSC C5149201
LOGO1: SpeedyLabs; logo
LOGO2: PicoFox; picofox_small
R1, R2, R3, R4: 27R; R_0402_1005Metric; LCSC C137890
R5, R6: 1k; R_0402_1005Metric; LCSC C11702
R7: 4K7; R_0402_1005Metric; LCSC C25900
R8, R9: 10k; R_0402_1005Metric; LCSC C25744
R10: 910K; R_0402_1005Metric; LCSC C25800
R11: 470R; R_0402_1005Metric; LCSC C25117
R12: 4.7M; R_0402_1005Metric; LCSC C474132
R13, R14: 5k1; R_0402_1005Metric; LCSC C25905
SW1: TS24CA; SW-SMD_TS24CA; LCSC Part C393942
SW2: SS-12D07-L5-B; SW-TH_SS-12D07-X-X; LCSC Part C480345
SW3, SW4, SW5, SW6, SW7, SW8: GT-TC152A-H085-L1; SW-TH_4P-L12.0-W12.0-P5.00-LS12.5; LCSC Part C2843937
U1: RP2040; RP2040-QFN-56; LCSC C2040
U2: SN74LV1T34DBVR; SOT-23-5_L2.9-W1.6-P0.95-LS2.8-BR; LCSC Part C100024
U3: W25Q128JVS; SOIC-8_5.23x5.23mm_P1.27mm; LCSC C131025
U4: XC6206PxxxMR-Regulator_Linear; SOT-23; LCSC C5446
U5: USBLC6-2SC6; SOT-23-6; LCSC C2827654
USB1: USB-AF-90-10X15.7-H5.72-CB; USB-A-SMD_C41014; LCSC Part C41014
USBC1: TYPE-C-31-M-12; USB-C_SMD-TYPE-C-31-M-12; LCSC Part C165948
Y1: 12MHz; Crystal_SMD_3225-4Pin_3.2x2.5mm; LCSC C9002

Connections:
+1V1: C5.1, C8.1, C10.1, U1.23 (DVDD), U1.45 (VREG_VOUT), U1.50 (DVDD)
+3V3: C3.1, C4.2, C12.1, C13.1, C14.1, C15.1, C16.1, C18.1, C19.1, C20.1, C21.1, C24.1, C25.1, D1.1 (K), FPC1.20, FPC1.22, FPC1.25, R7.2, R8.2, R9.1, U1.1 (IOVDD), U1.10 (IOVDD), U1.22 (IOVDD), U1.26 (~RUN), U1.33 (IOVDD), U1.42 (IOVDD), U1.43 (ADC_AVDD), U1.44 (VREG_VIN), U1.48 (USB_VDD), U1.49 (IOVDD), U3.8 (VCC), U4.2 (VO)
+5V: C1.2, C2.2, C26.1, C27.1, C28.1, C29.1, C30.1, C31.1, C32.1, C33.1, C34.1, C35.1, C36.1, C37.1, C38.1, C39.1, C40.1, C41.1, C42.1, C43.1, C44.1, C45.1, C46.1, C47.1, C48.1, C49.1, C50.1, C51.1, C52.1, C53.1, CN1.2, F1.1, F2.2, F3.1, LED1.1 (VDD), LED2.1 (VDD), LED3.1 (VDD), LED4.1 (VDD), LED5.1 (VDD), LED6.1 (VDD), LED7.1 (VDD), LED8.1 (VDD), LED9.1 (VDD), LED10.1 (VDD), LED11.1 (VDD), LED12.1 (VDD), LED13.1 (VDD), LED14.1 (VDD), LED15.1 (VDD), LED16.1 (VDD), LED17.1 (VDD), LED18.1 (VDD), LED19.1 (VDD), LED20.1 (VDD), LED21.1 (VDD), LED22.1 (VDD), LED23.1 (VDD), LED24.1 (VDD), LED25.1 (VDD), LED26.1 (VDD), LED27.1 (VDD), LED28.1 (VDD), U2.5 (VCC), U4.3 (VI), U5.5 (VBUS)
/D_+: R1.2, U1.47 (D+)
/D_-: R2.2, U1.46 (D-)
/GPIO4: CH14.1, U1.6 (GPIO4)
/GPIO5: SW2.3, U1.7 (GPIO5)
/GPIO6: SW4.1 (A), SW4.2 (B), U1.8 (GPIO6)
/GPIO7: SW6.1 (A), SW6.2 (B), U1.9 (GPIO7)
/GPIO8: SW8.1 (A), SW8.2 (B), U1.11 (GPIO8)
/GPIO9: CH4.1, U1.12 (GPIO9)
/GPIO10: CH12.1, U1.13 (GPIO10)
/GPIO11: CH10.1, U1.14 (GPIO11)
/GPIO12: CH8.1, U1.15 (GPIO12)
/GPIO13: CH6.1, U1.16 (GPIO13)
/GPIO14: CH2.1, U1.17 (GPIO14)
/GPIO15: CH13.1, U1.18 (GPIO15)
/GPIO16: CH7.1, U1.27 (GPIO16)
/GPIO17: CH9.1, U1.28 (GPIO17)
/GPIO18: CH11.1, U1.29 (GPIO18)
/GPIO19: CH5.1, U1.30 (GPIO19)
/GPIO20: CH3.1, U1.31 (GPIO20)
/GPIO21: U1.32 (GPIO21), U2.2 (A)
/GPIO22: CH1.1, U1.34 (GPIO22)
/GPIO23: SW3.1 (A), SW3.2 (B), U1.35 (GPIO23)
/GPIO24: SW5.1 (A), SW5.2 (B), U1.36 (GPIO24)
/GPIO25: SW7.1 (A), SW7.2 (B), U1.37 (GPIO25)
/GPIO26: CN1.3, U1.38 (GPIO26/ADC0)
/GPIO27: CN1.4, U1.39 (GPIO27/ADC1)
/GPIO28: CN1.5, U1.40 (GPIO28/ADC2)
/GPIO29: CN1.6, U1.41 (GPIO29/ADC3)
/XTAL_O: C7.2, R6.1, Y1.1
/~USB_BOOT: R5.1, SW1.4
CS: R5.2, U1.56 (QSPI_SS_N), U3.1 (~CS)
D_N: R2.1, U5.3 (I/O2)
D_P: R1.1, U5.1 (I/O1)
D_USB_N: CN2.3, U5.4 (I/O2), USBC1.A7 (DN1), USBC1.B7 (DN2)
D_USB_N2: R4.2, U1.4 (GPIO2)
D_USB_P: CN2.4, U5.6 (I/O1), USBC1.A6 (DP1), USBC1.B6 (DP2)
D_USB_P2: R3.2, U1.5 (GPIO3)
GND: C1.1, C2.1, C3.2, C4.1, C5.2, C6.1, C7.1, C8.2, C10.2, C12.2, C13.2, C14.2, C15.2, C16.2, C17.2, C18.2, C19.2, C20.2, C21.2, C22.1, C23.1, C24.2, C25.2, C26.2, C27.2, C28.2, C29.2, C30.2, C31.2, C32.2, C33.2, C34.2, C35.2, C36.2, C37.2, C38.2, C39.2, C40.2, C41.2, C42.2, C43.2, C44.2, C45.2, C46.2, C47.2, C48.2, C49.2, C50.2, C51.2, C52.2, C53.2, C54.2, CH1.2, CH2.2, CH3.2, CH4.2, CH5.2, CH6.2, CH7.2, CH8.2, CH9.2, CH10.2, CH11.2, CH12.2, CH13.2, CH14.2, CN1.1, CN1.8, CN1.9, CN2.1, CN2.6, CN2.7, CN2.8, CN2.9, FPC1.1, FPC1.2, FPC1.6, FPC1.7, FPC1.8, FPC1.9, FPC1.10, FPC1.14, FPC1.15, FPC1.16, FPC1.18, FPC1.19, FPC1.21, FPC1.23, FPC1.30, FPC1.31, FPC1.32, LED1.4 (VSS), LED2.4 (VSS), LED3.4 (VSS), LED4.4 (VSS), LED5.4 (VSS), LED6.4 (VSS), LED7.4 (VSS), LED8.4 (VSS), LED9.4 (VSS), LED10.4 (VSS), LED11.4 (VSS), LED12.4 (VSS), LED13.4 (VSS), LED14.4 (VSS), LED15.4 (VSS), LED16.4 (VSS), LED17.4 (VSS), LED18.4 (VSS), LED19.4 (VSS), LED20.4 (VSS), LED21.4 (VSS), LED22.4 (VSS), LED23.4 (VSS), LED24.4 (VSS), LED25.4 (VSS), LED26.4 (VSS), LED27.4 (VSS), LED28.4 (VSS), R10.1, R12.2, R13.1, R14.2, SW1.1, SW1.2, SW1.3, SW2.1, SW2.2, SW2.EH, SW3.3 (C), SW3.4 (D), SW4.3 (C), SW4.4 (D), SW5.3 (C), SW5.4 (D), SW6.3 (C), SW6.4 (D), SW7.3 (C), SW7.4 (D), SW8.3 (C), SW8.4 (D), U1.19 (TESTEN), U1.57 (GND), U2.3 (GND), U3.4 (GND), U4.1 (GND), U5.2 (GND), USB1.4 (GND), USB1.5, USB1.6, USB1.7, USB1.8, USBC1.0 (SH), USBC1.1 (SH), USBC1.2 (SH), USBC1.3 (SH), USBC1.A1 (GND), USBC1.A12 (GND), USBC1.B1 (GND), USBC1.B12 (GND), Y1.2, Y1.4
LED_DATA: R11.1, U2.4 (Y)
LED_DATA_END: CN1.7, LED21.2 (DOUT)
unnamed: C9.1, FPC1.28
unnamed: C9.2, FPC1.29
unnamed: C11.1, FPC1.26
unnamed: C11.2, FPC1.27
unnamed: C22.2, FPC1.4
unnamed: C23.2, FPC1.3
unnamed: C54.1, H8.1, R12.1
unnamed: CN2.2, CN2.5, F2.1
unnamed: FPC1.5, R10.2
unnamed: LED1.3 (DIN), R11.2
unnamed: LED1.2 (DOUT), LED8.3 (DIN)
unnamed: LED2.3 (DIN), LED22.2 (DOUT)
unnamed: LED2.2 (DOUT), LED9.3 (DIN)
unnamed: LED3.2 (DOUT), LED10.3 (DIN)
unnamed: LED10.2 (DOUT), LED12.3 (DIN)
unnamed: LED11.3 (DIN), LED18.2 (DOUT)
unnamed: LED4.3 (DIN), LED11.2 (DOUT)
unnamed: LED5.3 (DIN), LED12.2 (DOUT)
unnamed: LED13.3 (DIN), LED20.2 (DOUT)
unnamed: LED6.3 (DIN), LED13.2 (DOUT)
unnamed: LED14.3 (DIN), LED17.2 (DOUT)
unnamed: LED7.3 (DIN), LED14.2 (DOUT)
unnamed: LED8.2 (DOUT), LED15.3 (DIN)
unnamed: LED15.2 (DOUT), LED22.3 (DIN)
unnamed: LED9.2 (DOUT), LED16.3 (DIN)
unnamed: LED16.2 (DOUT), LED23.3 (DIN)
unnamed: LED17.3 (DIN), LED24.2 (DOUT)
unnamed: LED18.3 (DIN), LED25.2 (DOUT)
unnamed: LED19.3 (DIN), LED26.2 (DOUT)
unnamed: LED19.2 (DOUT), LED28.3 (DIN)
unnamed: LED20.3 (DIN), LED27.2 (DOUT)
unnamed: LED21.3 (DIN), LED28.2 (DOUT)
unnamed: LED3.3 (DIN), LED23.2 (DOUT)
unnamed: LED4.2 (DOUT), LED24.3 (DIN)
unnamed: LED5.2 (DOUT), LED25.3 (DIN)
unnamed: LED6.2 (DOUT), LED26.3 (DIN)
unnamed: LED7.2 (DOUT), LED27.3 (DIN)
unnamed: R3.1, USB1.3 (D+)
unnamed: R4.1, USB1.2 (D-)
unnamed: F1.2, USB1.1 (VCC)
unnamed: R13.2, USBC1.A5 (CC1)
unnamed: R14.1, USBC1.B5 (CC2)
OLED_Reset: C17.1, D1.2 (A), FPC1.17, R7.1
QSPI_CLK: U1.52 (QSPI_SCLK), U3.6 (CLK)
SCL: FPC1.13, R8.1, U1.3 (GPIO1)
SD0: U1.53 (QSPI_SD0), U3.5 (DI(IO0))
SD1: U1.55 (QSPI_SD1), U3.2 (DO(IO1))
SD2: U1.54 (QSPI_SD2), U3.3 (IO2)
SD3: U1.51 (QSPI_SD3), U3.7 (IO3)
SDA: FPC1.11, FPC1.12, R9.2, U1.2 (GPIO0)
SWCLK: U1.24 (SWCLK)
SWD: U1.25 (SWDIO)
VBUS_C: F3.2, USBC1.A4 (VBUS), USBC1.A9 (VBUS), USBC1.B4 (VBUS), USBC1.B9 (VBUS)
XTAL_IN: C6.2, U1.20 (XTAL_IN), Y1.3
XTAL_OUT: R6.2, U1.21 (XTAL_OUT)

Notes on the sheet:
OLED ZIF
Aux Switches
Neopixel Signal Boost
RP2040 Flash
Toggle Switch
Graphics and Mounting
WASD Breakout (ZH)
USB Passthrough
5v -> 3v3
pins must support i2c
USB Input (ZH)
RP2040 Crystal
USB ESD Protection
pins must be sequential
Neopixels
RP2040 Decoupling Caps
USB Input (C)
Main Switches

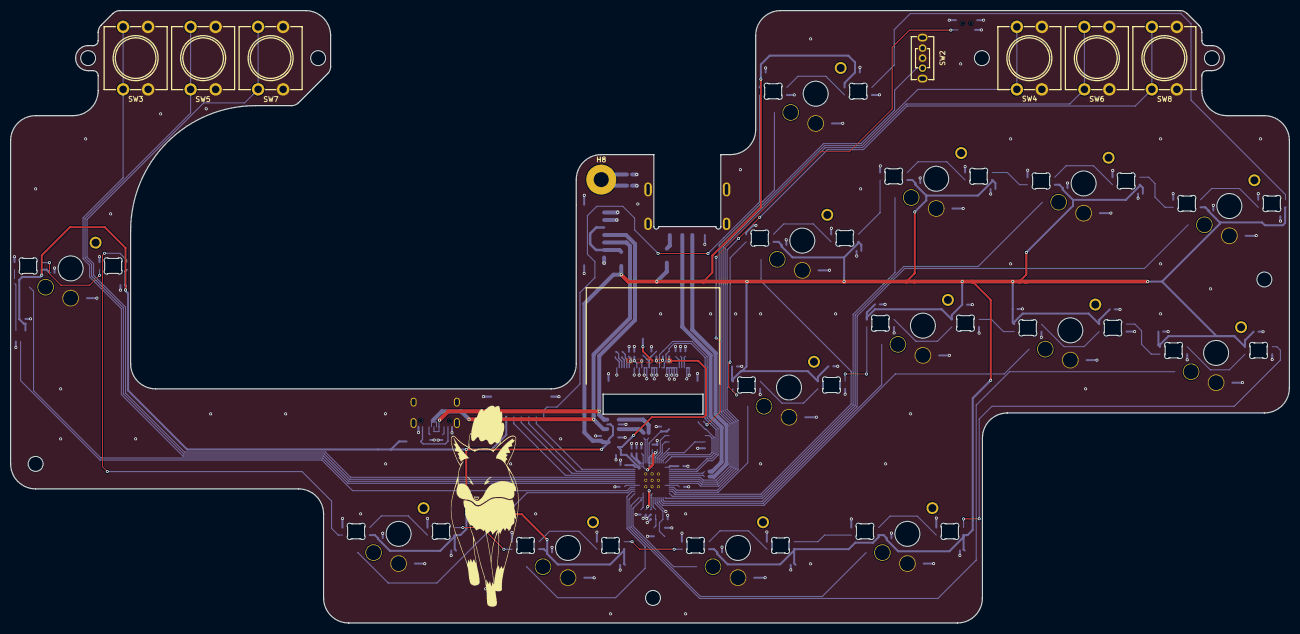
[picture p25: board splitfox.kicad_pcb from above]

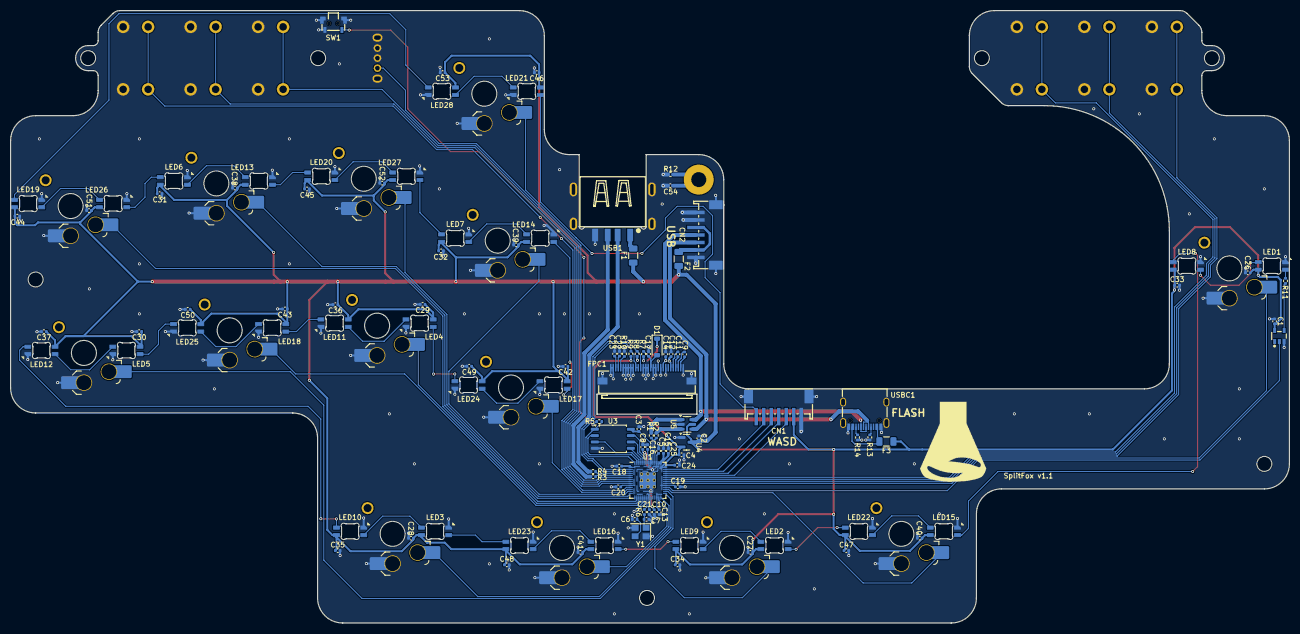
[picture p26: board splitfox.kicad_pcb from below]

Board: 2 copper layers, 255.8 x 122.5 mm, 143 parts (127 on the bottom side), 96 nets.

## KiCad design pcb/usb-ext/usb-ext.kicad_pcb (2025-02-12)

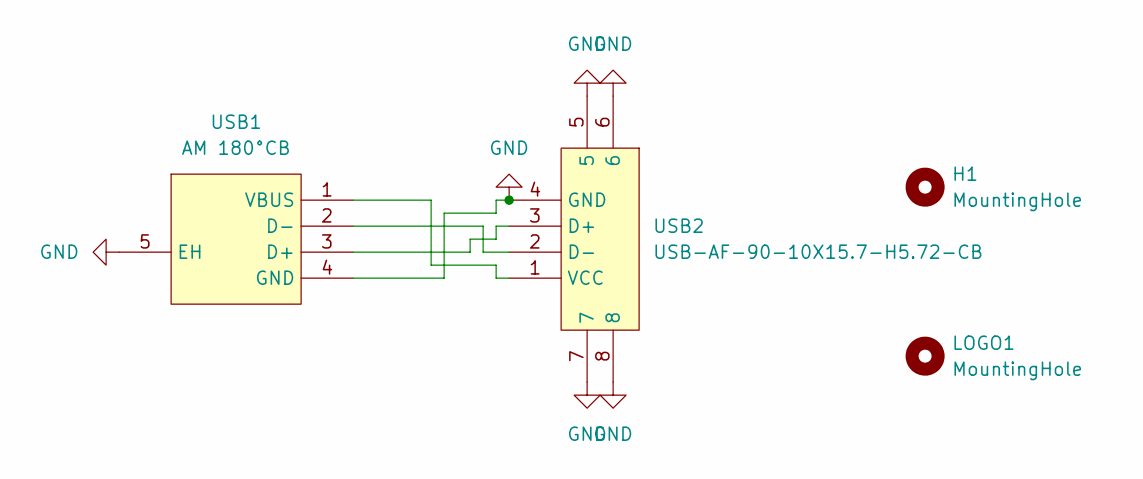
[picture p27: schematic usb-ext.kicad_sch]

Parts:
H1: MountingHole; MountingHole_3mm
LOGO1: MountingHole; logo_small
USB1: AM 180°CB; USB-SMD_AM180CB; LCSC Part C2681565
USB2: USB-AF-90-10X15.7-H5.72-CB; USB-A-SMD_C41014; LCSC Part C41014

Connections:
GND: USB1.4 (GND), USB1.5 (EH), USB2.4 (GND), USB2.5, USB2.6, USB2.7, USB2.8
unnamed: USB1.3 (D+), USB2.3 (D+)
unnamed: USB1.2 (D-), USB2.2 (D-)
unnamed: USB1.1 (VBUS), USB2.1 (VCC)

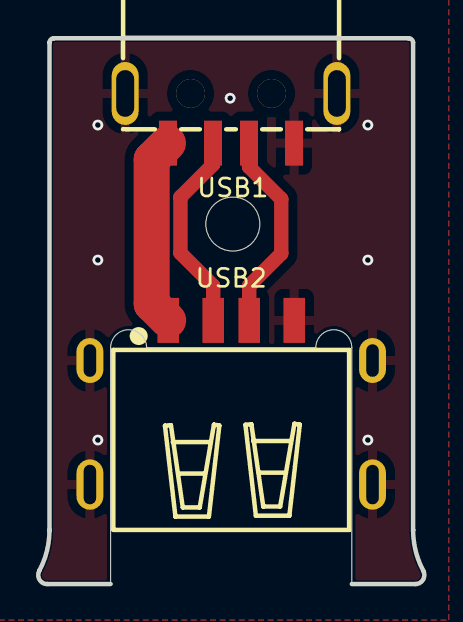
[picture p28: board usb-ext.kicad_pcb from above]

Board: 2 copper layers, 21.4 x 30.3 mm, 4 parts (1 on the bottom side), 4 nets.

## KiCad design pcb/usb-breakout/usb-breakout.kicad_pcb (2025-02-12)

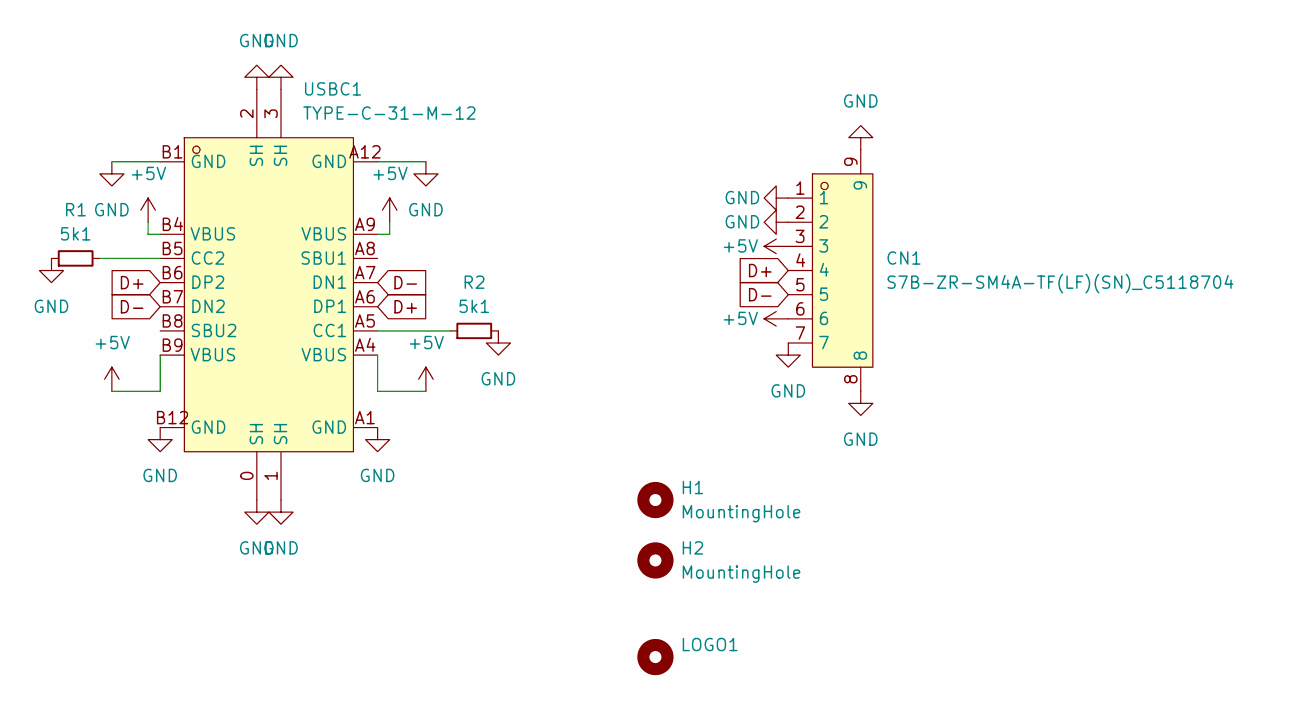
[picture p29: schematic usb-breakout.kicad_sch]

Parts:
CN1: S7B-ZR-SM4A-TF(LF)(SN)_C5118704; CONN-SMD_S7B-ZR-SM4A-TF-LF-SN; LCSC Part C5118704
H1, H2: MountingHole; MountingHole_3mm
LOGO1: MountingHole; logo_small
R1, R2: 5k1; R_0402_1005Metric_Pad0.72x0.64mm_HandSolder; LCSC C25905
USBC1: TYPE-C-31-M-12; USB-C_SMD-TYPE-C-31-M-12; LCSC Part C165948

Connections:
+5V: CN1.3, CN1.6, USBC1.A4 (VBUS), USBC1.A9 (VBUS), USBC1.B4 (VBUS), USBC1.B9 (VBUS)
D+: CN1.4, USBC1.A6 (DP1), USBC1.B6 (DP2)
D-: CN1.5, USBC1.A7 (DN1), USBC1.B7 (DN2)
GND: CN1.1, CN1.2, CN1.7, CN1.8, CN1.9, R1.1, R2.2, USBC1.0 (SH), USBC1.1 (SH), USBC1.2 (SH), USBC1.3 (SH), USBC1.A1 (GND), USBC1.A12 (GND), USBC1.B1 (GND), USBC1.B12 (GND)
unnamed: R2.1, USBC1.A5 (CC1)
unnamed: R1.2, USBC1.B5 (CC2)

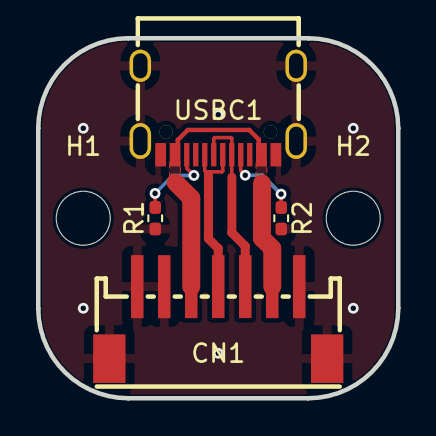
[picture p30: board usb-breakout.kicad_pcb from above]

Board: 2 copper layers, 20.0 x 20.0 mm, 7 parts (1 on the bottom side), 6 nets.

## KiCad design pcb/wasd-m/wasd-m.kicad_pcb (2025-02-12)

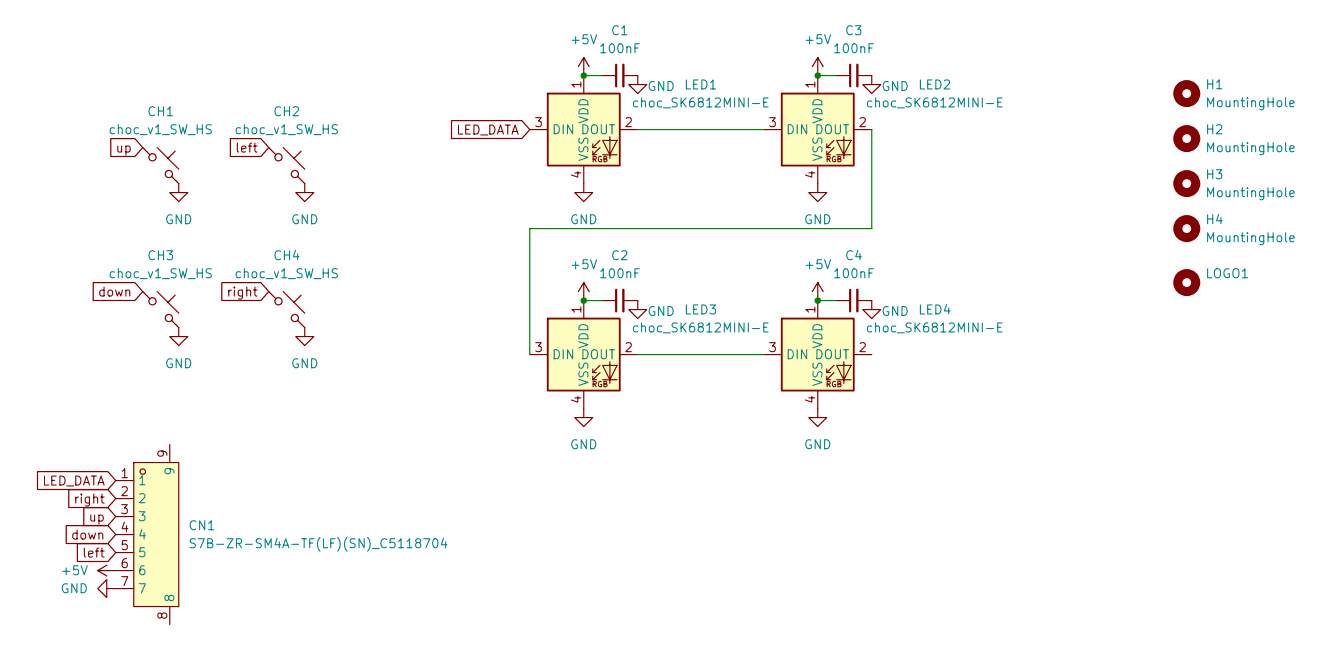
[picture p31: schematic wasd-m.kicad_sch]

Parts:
C1, C2, C3, C4: 100nF; C_0402_1005Metric; LCSC C1525
CH1, CH2, CH3, CH4: choc_v1_SW_HS; SW_choc_v2_HS_CPG135001S30_1u; LCSC C5333465
CN1: S7B-ZR-SM4A-TF(LF)(SN)_C5118704; CONN-SMD_S7B-ZR-SM4A-TF-LF-SN; LCSC Part C5118704
H1, H2, H3, H4: MountingHole; MountingHole_3mm
LED1, LED2, LED3, LED4: choc_SK6812MINI-E; LED_choc_6028R; LCSC C5149201
LOGO1: MountingHole; logo_small

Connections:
+5V: C1.1, C2.1, C3.1, C4.1, CN1.6, LED1.1 (VDD), LED2.1 (VDD), LED3.1 (VDD), LED4.1 (VDD)
GND: C1.2, C2.2, C3.2, C4.2, CH1.2, CH2.2, CH3.2, CH4.2, CN1.7, LED1.4 (VSS), LED2.4 (VSS), LED3.4 (VSS), LED4.4 (VSS)
LED_DATA: CN1.1, LED1.3 (DIN)
unnamed: LED1.2 (DOUT), LED2.3 (DIN)
unnamed: LED2.2 (DOUT), LED3.3 (DIN)
unnamed: LED3.2 (DOUT), LED4.3 (DIN)
down: CH3.1, CN1.4
left: CH2.1, CN1.5
right: CH4.1, CN1.2
up: CH1.1, CN1.3

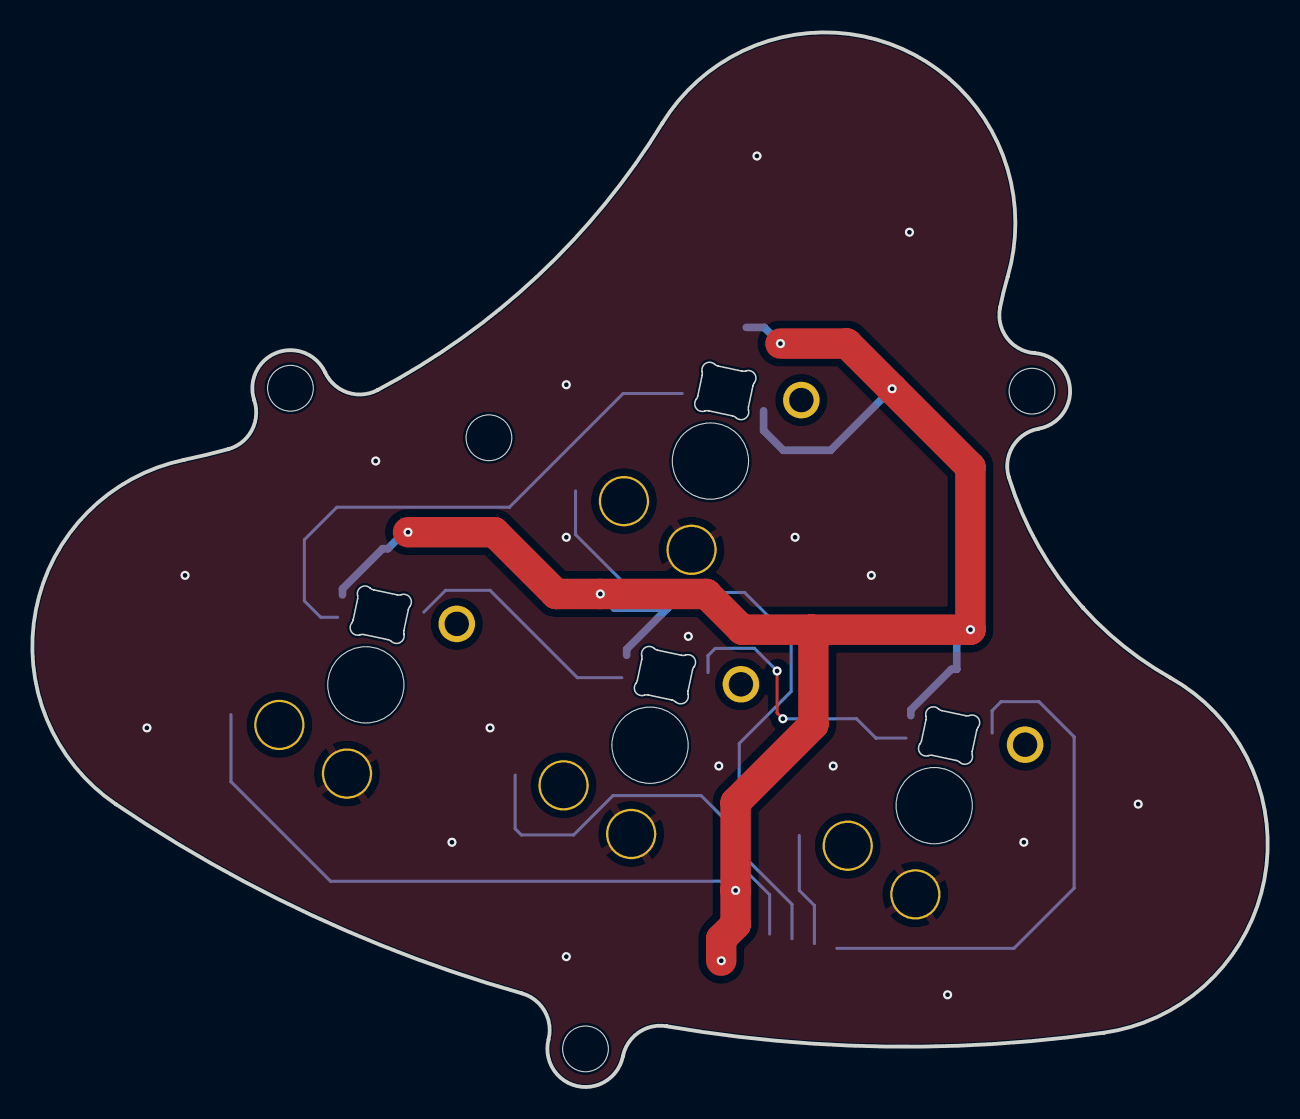
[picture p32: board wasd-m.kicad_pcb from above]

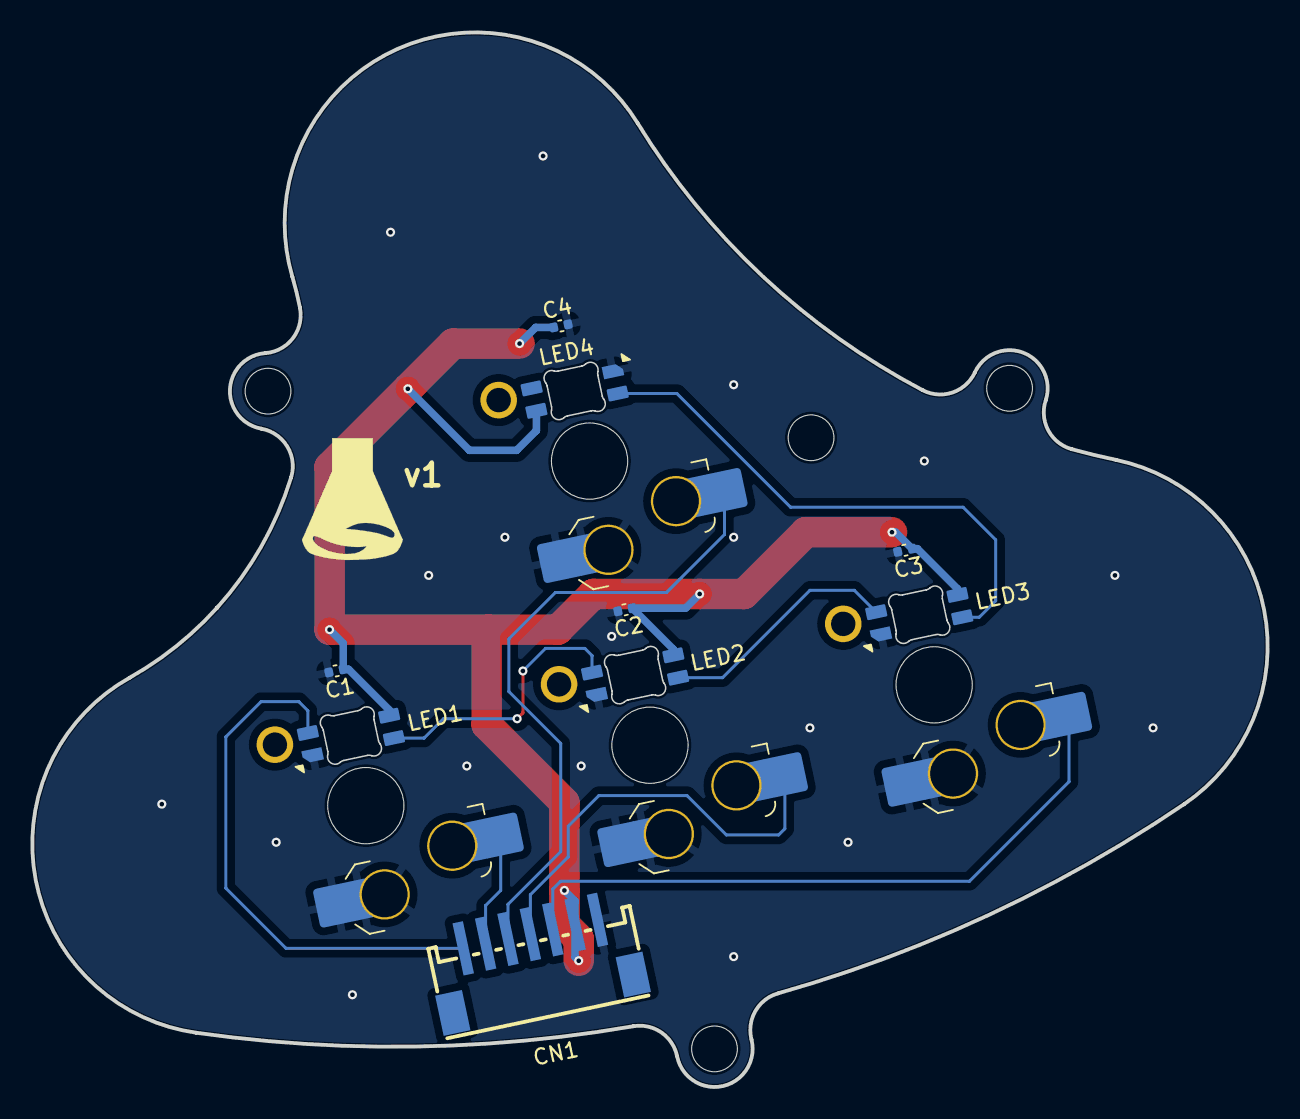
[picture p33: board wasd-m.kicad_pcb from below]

Board: 2 copper layers, 81.0 x 69.2 mm, 18 parts (18 on the bottom side), 10 nets.

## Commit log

2025-01-18 NG | WIP Base Cad
    [HautePad M16 Lite-top.dwg, HautePad M16 Ultra-top.dwg, R16-facetemplate.dwg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]
2025-01-20 NG | RGB and wasd tweaks
    [splitfox-base.SLDPRT]
2025-01-22 NG | PCB shape
    [splitfox-base.SLDPRT]
2025-01-30 NG | Honson F5 cad, updated splitfox-base, consider going bottom single load after today
    [honson-f5.SLDPRT, mlite.SLDPRT, multra.SLDPRT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]
2025-02-02 NG | Move to bottom assembly + through hole tops
    [splitfox-base.SLDPRT]
2025-02-02 NG | Enclosure finished
    [honson-f5.SLDPRT, splitfox-base.SLDPRT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]
2025-02-03 NG | USB Boards
    [bom.csv, designators.csv, positions.csv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]
2025-02-03 NG | WASD wip, led issue
    [wasd.kicad_pcb, wasd.kicad_sch]
2025-02-03 NG | Updated layouts with leds, todo: pcb layout
    [splitfox-base.SLDPRT, splitfox-body.SLDPRT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]
2025-02-03 NG | wasd pcb
    [wasd.kicad_pcb, wasd.kicad_sch]
2025-02-04 NG | Update usb ext pinout, cleanup
    [bom.csv, designators.csv, positions.csv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]
2025-02-04 NG | Cad assembly updated, ready for main pcb
    [bom.csv, designators.csv, positions.csv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]
2025-02-10 NG | SplitFox Schematic
    [splitfox.kicad_pcb, splitfox.kicad_sch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]
2025-02-11 NG | Splitfox PCB Placement
    [bom.csv, splitfox.kicad_pcb, splitfox.kicad_sch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]
2025-02-12 NG | DRC Cleanup
    [usb-breakout-pcb.SLDASM, usb-breakout.kicad_pcb, usb-breakout.step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]
2025-02-12 NG | Ready for routing
    [splitfox.kicad_pcb]
2025-02-12 NG | SplitFox PCB, Redid body cad
    [bom.csv, designators.csv, positions.csv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]
2025-02-12 NG | Fixed assembly, dongle should go in 2.5667mm more and usb_ext needs to be adjusted
2025-02-12 NG | It's done-ish, pcb tweaks, assembly
    [Kailh_PG1353.SLDPRT, concave_22-5.SLDPRT, concave_28-5.SLDPRT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]
2025-02-13 NG | ESD/EMI caps, USB C flash port
    [bom.csv, designators.csv, positions.csv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]
2025-02-13 NG | Assembly fixed, MIX assembly
    [1u.SLDPRT, splitfox-body.SLDPRT, splitfox-top-m.DXF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]
2025-02-13 NG | Body Print Test
    [splitfox-body - Copy (2).3MF, splitfox-body - Copy (2).SLDPRT, splitfox-body - Copy (3).3MF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]
2025-02-14 NG | mix plate test
    [splitfox-wasd-m.3MF]
2025-02-15 NG | 2.5mm acrylics, art dxf
    [splitfox-bottom.SLDPRT, splitfox-top-art.DXF, splitfox-top-m-art.DXF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]
2025-02-15 NG | Test acrylic laser exports
    [splitfox-bottom.DXF, splitfox-top-art.DXF, splitfox-top-m-art.DXF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]
2025-03-01 NG | Test foot print
    [splitfox-foot.3MF]
2025-03-10 NG | CAD Exports
    [splitfox-body.STEP, splitfox-bottom.STEP, splitfox-foot-2mm.DXF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]
2025-03-11 NG | USB-EXT housing
    [usb-ext-assem.SLDASM, usb-ext-bot.3MF, usb-ext-bot.SLDPRT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]
2025-03-11 NG | usb ext fixes, exports
    [usb-ext-assem.SLDASM, usb-ext-bot.3MF, usb-ext-bot.SLDPRT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]
2025-03-11 NG | Further fixes to usb-ext housing
    [usb-ext-assem.SLDASM, usb-ext-bot.3MF, usb-ext-bot.SLDPRT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]
2025-03-12 NG | 2.5mm plate test
    [splitfox-top-m-2_5.3MF]
2025-03-13 NG | Added spacer for wasd
    [93657A501_Nylon Unthreaded Spacer.3MF, 93657A501_Nylon Unthreaded Spacer.SLDPRT]
2025-03-15 NG | Added foot alignment tool
    [splitfox-foot-tool.3MF, splitfox-foot-tool.SLDPRT]
2025-03-15 NG | Added holes for foot tool when flipped
    [splitfox-foot-tool.3MF, splitfox-foot-tool.SLDPRT]
2025-03-17 NG | v1.1 SplitFox PCB - old crystal setup test
    [bom.csv, designators.csv, positions.csv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]
2025-03-18 NG | Foot Tool curve fixes
    [splitfox-foot-tool.3MF, splitfox-foot-tool.SLDPRT]
2025-04-08 NG | Test web ui rgb led firmware
